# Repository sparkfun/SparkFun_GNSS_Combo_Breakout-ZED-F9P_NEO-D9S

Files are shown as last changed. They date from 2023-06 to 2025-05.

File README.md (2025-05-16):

# SparkFun u-blox ZED-F9P NEO-D9S Combo Breakout

<p align="center">
  <a href="https://github.com/sparkfun/SparkFun_GNSS_Combo_Breakout-ZED-F9P_NEO-D9S/issues" alt="Issues">
    </a>
  <a href="https://github.com/sparkfun/SparkFun_GNSS_Combo_Breakout-ZED-F9P_NEO-D9S/actions" alt="Actions">
    </a>
  <a href="https://github.com/sparkfun/SparkFun_GNSS_Combo_Breakout-ZED-F9P_NEO-D9S/blob/main/LICENSE.md" alt="License">
    </a>
  <a href="https://twitter.com/intent/follow?screen_name=sparkfun">
    </a>
</p>

SparkFun u-blox ZED-F9P NEO-D9S Combo Breakout (https://www.sparkfun.com/products/22560)

*[SparkFun u-blox ZED-F9P NEO-D9S Combo Breakout (GPS-22560)](https://www.sparkfun.com/products/22560)*

The [SparkFun u-blox ZED-F9P NEO-D9S Combo Breakout (GPS-22560)](https://www.sparkfun.com/products/22560) combines the u-blox ZED-F9P multi-band high precision GNSS module with the NEO-D9S L-band GNSS correction data receiver. With a clear view of the sky, especially a clear view to the South, this combo breakout will deliver centimeter-level accuracy positioning without needing separate RTK or NTRIP corrections.

The Combo Breakout is designed to work with u-blox's PointPerfect L-band satellite GNSS augmentation service, which provides homogeneous coverage in contiguous USA.

### Important Note:

u-blox provides products and services to "B2B Customers". Only business customers are eligible to register for a Thingstream (PointPerfect) account. You may be required to demonstrate that the use of the combo breakout is in relation to your trade, business, craft or profession. u-blox products and services are not intended for individual consumer use.

## Repository Contents

* **[/docs](/docs/)** - Online documentation files
    * [board_files](/docs/assets/board_files/) - Files for the product design
        * [Eagle design files](https://github.com/sparkfun/SparkFun_GNSS_Combo_Breakout-ZED-F9P_NEO-D9S/blob/main/docs/assets/board_files/ZED-F9P_NEO-D9S_Combo_x02.zip) (.zip)
        * [Schematic](https://github.com/sparkfun/SparkFun_GNSS_Combo_Breakout-ZED-F9P_NEO-D9S/blob/main/docs/assets/board_files/SparkFun_GNSS_Combo_Breakout-ZED-F9P_NEO-D9S_Schematic.pdf) (.pdf)
        * [Dimensions](https://github.com/sparkfun/SparkFun_GNSS_Combo_Breakout-ZED-F9P_NEO-D9S/blob/main/docs/assets/board_files/SparkFun_GNSS_Combo_Breakout-ZED-F9P_NEO-D9S_Dimensions.pn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) (.png)
* **[/Hardware](/Hardware/)** - Eagle design files (.brd, .sch)

## Documentation

* **[Hookup Guide (mkdocs)](http://docs.sparkfun.com/SparkFun_GNSS_Combo_Breakout-ZED-F9P_NEO-D9S/)** - Hookup guide for the SparkFun u-blox ZED-F9P NEO-D9S Combo Breakout hosted by GitHub pages.

## Product Versions

* [GPS-22560](https://www.sparkfun.com/products/22560) - Initial SparkFun Release

## License Information

This product is _**open source**_! 

Please review the LICENSE.md file for license information. 

If you have any questions or concerns on licensing, please contact technical support on our [SparkFun forums](https://forum.sparkfun.com/viewforum.php?f=152).

Distributed as-is; no warranty is given.

- Your friends at SparkFun.

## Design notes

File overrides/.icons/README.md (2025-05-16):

.icons directory
====================
This folder should contain branding logos for the product documentation

## General Images
- `sfe.svg` - SparkFun flame logo
- `kicad-primary.svg` - Full KiCad logo

## Directory
- `logo` - Other available logos

## SVG Optimizer
- [Remove meta data from svg](https://jakearchibald.github.io/svgomg/)

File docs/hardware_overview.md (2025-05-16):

<figure markdown>
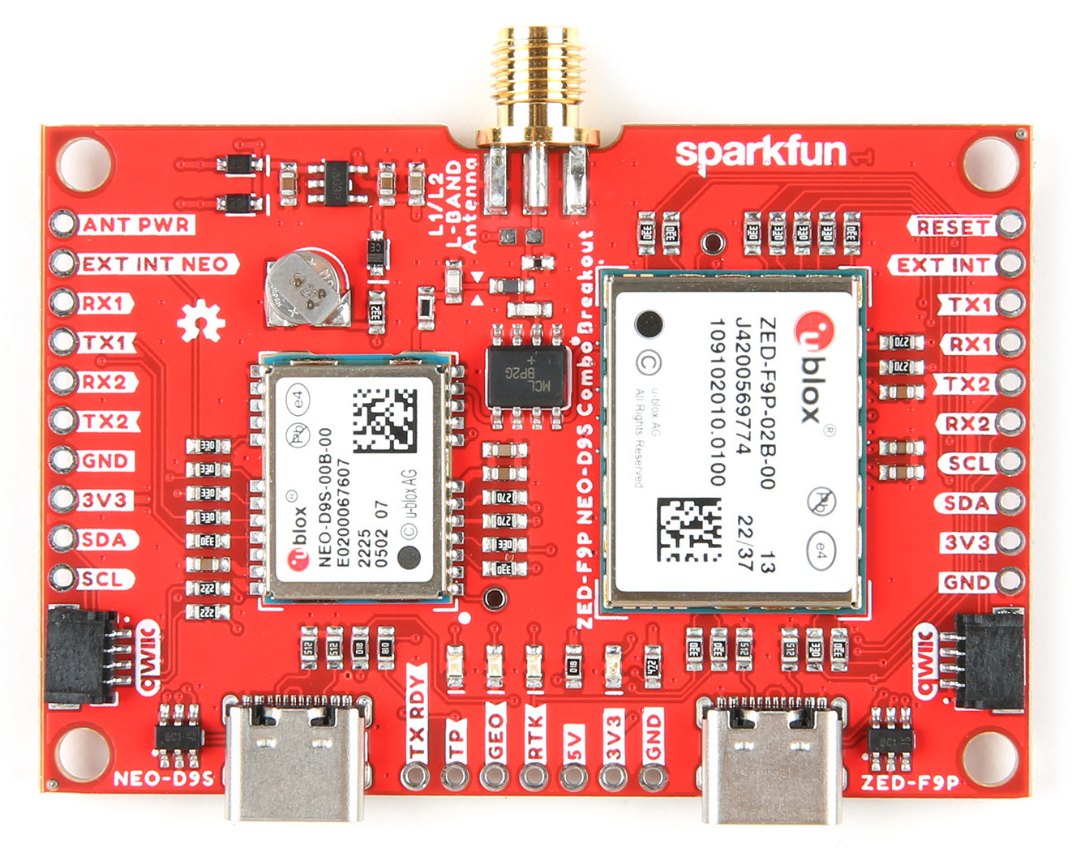
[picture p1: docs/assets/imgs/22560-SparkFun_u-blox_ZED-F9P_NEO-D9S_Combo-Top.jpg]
Combo Breakout PCB

<figcaption markdown>
The Combo Breakout PCB.
</figcaption>
</figure>

The u-blox ZED-F9P NEO-D9S Combo Breakout is a sophisticated yet compact GNSS board. The following is a summary of its features and functions:

* **`ZED-F9P`** - the ZED-F9P is a top-of-the-line module for high accuracy GNSS and GPS location solutions
    * Concurrent reception of GPS, GLONASS, Galileo and BeiDou
    * Multi-band RTK with fast convergence times and reliable performance
    * Centimeter-level accuracy in a small and energy-efficient module

<figure markdown>
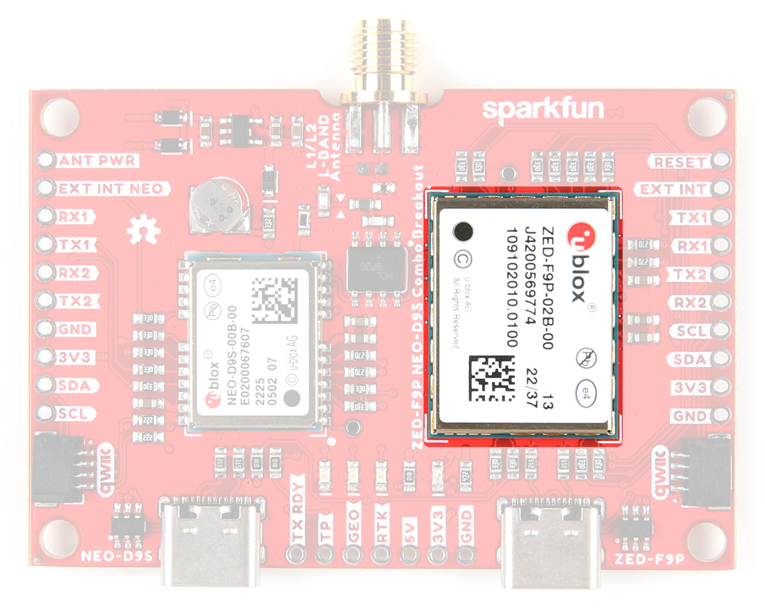
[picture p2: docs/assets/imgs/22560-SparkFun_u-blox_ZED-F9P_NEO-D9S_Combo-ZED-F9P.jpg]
ZED-F9P

<figcaption markdown>
The ZED-F9P GNSS module.
</figcaption>
</figure>

* **`NEO-D9S`** - the NEO-D9S is a satellite data receiver for L-band correction broadcast
    * The NEO-D9S can be configured for use with a variety of L-band correction services including u-blox's PointPerfect service
    * It decodes the satellite transmission and outputs a correction stream directly to the ZED-F9P via UART2

<figure markdown>
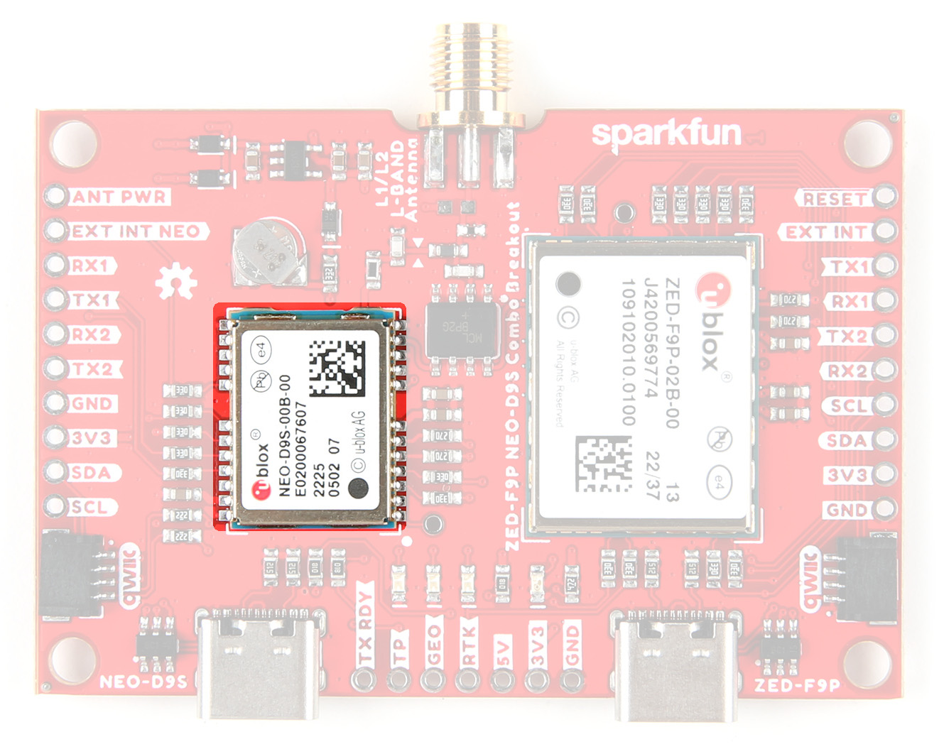
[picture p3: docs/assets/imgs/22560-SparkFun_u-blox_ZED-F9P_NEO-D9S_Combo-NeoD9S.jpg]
NEO-D9S

<figcaption markdown>
The NEO-D9S correction data receiver.
</figcaption>
</figure>

* **`UART2 TX and RX`** - the ZED-F9P and NEO-D9S UART2 TX and RX are interconnected (crossed-over) to allow the NEO to feed corrections directly to the ZED
    * The UART2 pins can be isolated if required by opening the **TX2** and **RX2** jumpers
    * Using UART2 to pass the correction data is recommended, but is optional. You can use UART1 or I<sup>2</sup>C instead if you want to. Our u-blox Arduino Library has an [example](https://github.com/sparkfun/SparkFun_u-blox_GNSS_v3/tree/main/examples/NEO-D9S_and_NEO-D9C/Example2_LBand_Corrections_with_NEO-D9S) which shows how to read the correction data from the NEO-D9S and push it to the ZED-F9P using I<sup>2</sup>C.

<figure markdown>
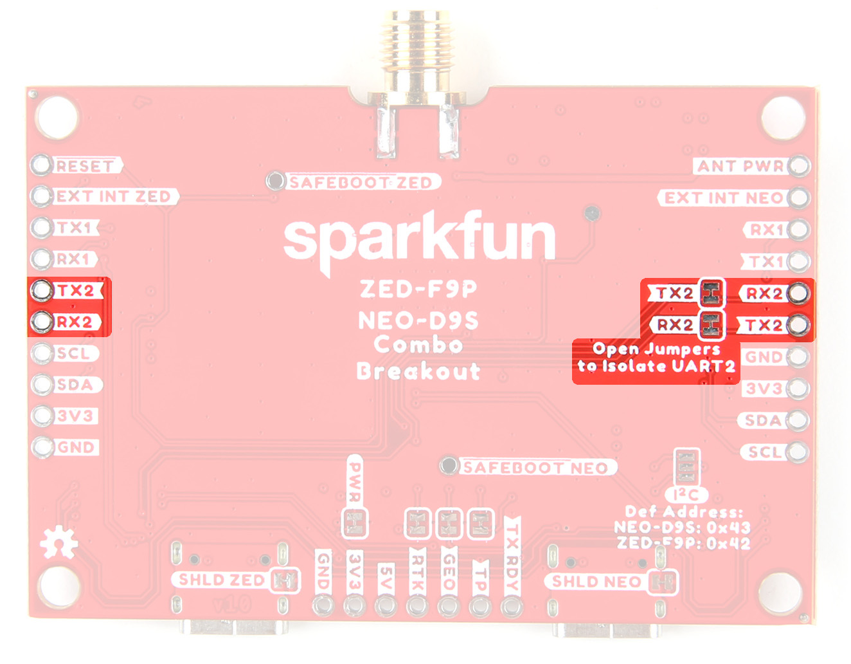
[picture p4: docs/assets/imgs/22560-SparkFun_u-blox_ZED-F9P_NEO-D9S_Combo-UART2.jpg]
UART2

<figcaption markdown>
The UART2 connections.
</figcaption>
</figure>

* **`Antenna Power Divider`** - the breakout has an on-board power divider (antenna splitter) to divide the satellite signals between the ZED and the NEO
    * The connector is SMA female (standard polarity)
    * 3.3V power is provided for an active antenna

<figure markdown>
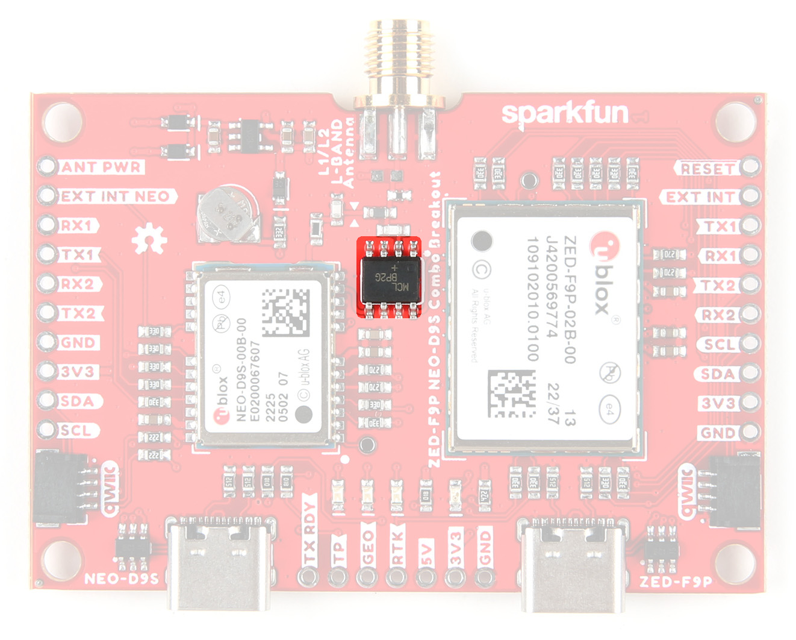
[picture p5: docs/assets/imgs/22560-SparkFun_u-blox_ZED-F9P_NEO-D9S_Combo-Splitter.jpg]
Splitter

<figcaption markdown>
The antenna splitter (power divider).
</figcaption>
</figure>

* **`Dual USB-C connections`** - one USB-C connector provides a direct connection to the ZED-F9P; the second provides a direct connection to the NEO-D9S
    * The board can be powered via either USB-C connector, or both
    * There is no on-board USB hub. Both ports can be connected simultaneously to the same computer, or different computers if desired

<figure markdown>
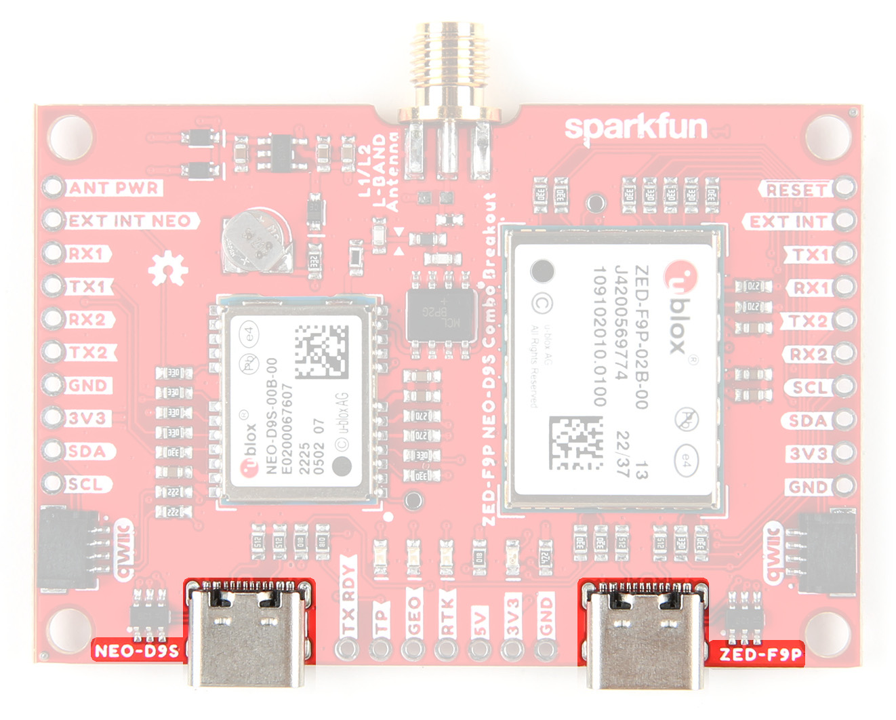
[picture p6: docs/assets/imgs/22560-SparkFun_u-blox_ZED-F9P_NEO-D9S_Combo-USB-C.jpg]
USB Connectors

<figcaption markdown>
The two USB-C connectors.
</figcaption>
</figure>

* **`LED Indicators`** - the breakout has four LED indicators:
    * **3V3** Power
    * **RTK**: Off = No Carrier Solution; Flashing = Floating Solution; On = Fixed Solution
    * **GEO**: Geofence indication
    * **TP**: Timing Pulse (Pulse Per Second)
    * Each LED can be disabled by opening the corresponding split pad jumper on the bottom of the breakout

<figure markdown>
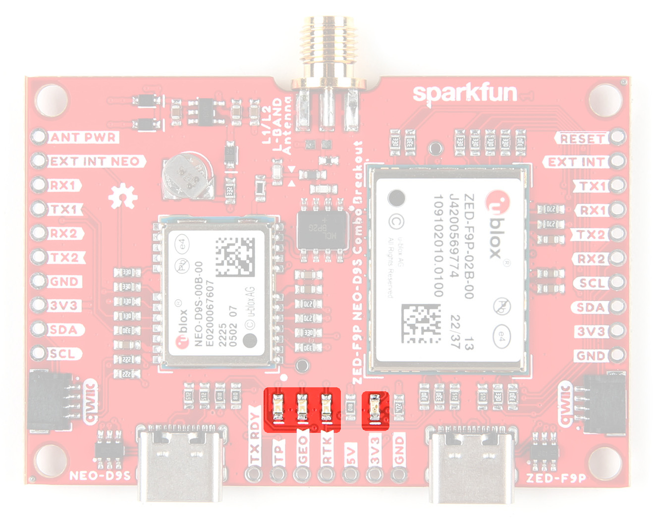
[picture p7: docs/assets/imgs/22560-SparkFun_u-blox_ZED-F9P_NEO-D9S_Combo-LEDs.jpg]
LEDs

<figcaption markdown>
The LEDs.
</figcaption>
</figure>

* **`Dual Qwiic Connectors`** - the breakout has two Qwiic (I<sup>2</sup>C) connectors allowing the breakout to be daisy-chained into your Qwiic project

<figure markdown>
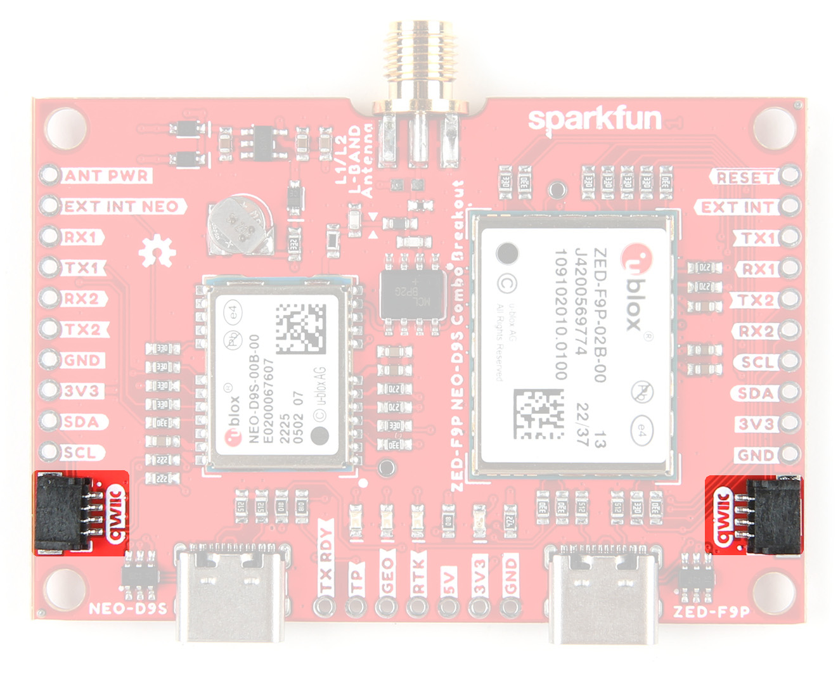
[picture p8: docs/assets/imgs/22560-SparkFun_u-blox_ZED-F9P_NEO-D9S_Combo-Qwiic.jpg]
Qwiic Connectors

<figcaption markdown>
The two Qwiic connectors.
</figcaption>
</figure>

* **`Back-up Battery`** - a small rechargeable coin cell maintains the ZED-F9P battery-backed RAM while the power is disconnected

<figure markdown>
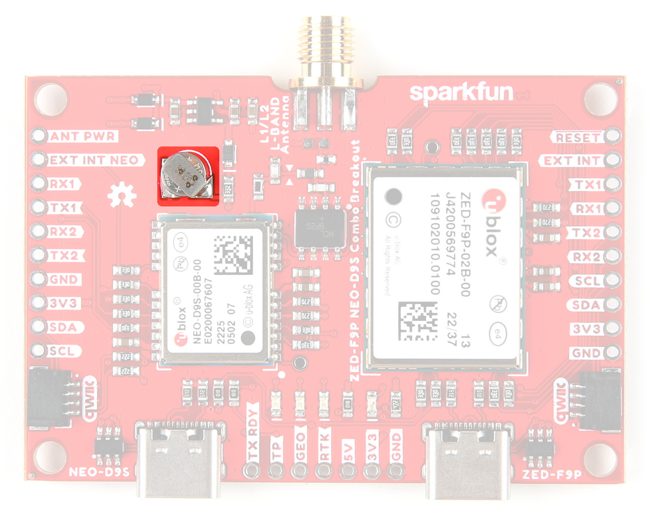
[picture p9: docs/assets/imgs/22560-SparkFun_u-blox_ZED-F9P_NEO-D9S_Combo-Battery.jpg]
Back-up Battery

<figcaption markdown>
The rechargeable back-up battery.
</figcaption>
</figure>

* **`Full set of breakout pads`** - the breakout pads provide full access to the ZED-F9P and NEO-D9S pins 
    * I<sup>2</sup>C
    * UART1
    * UART2
    * External Interrupt
    * Reset
    * Safeboot
    * ZED-F9P: TX_RDY, TP, GEO, RTK
    * Power: 5V and 3.3V

<figure markdown>
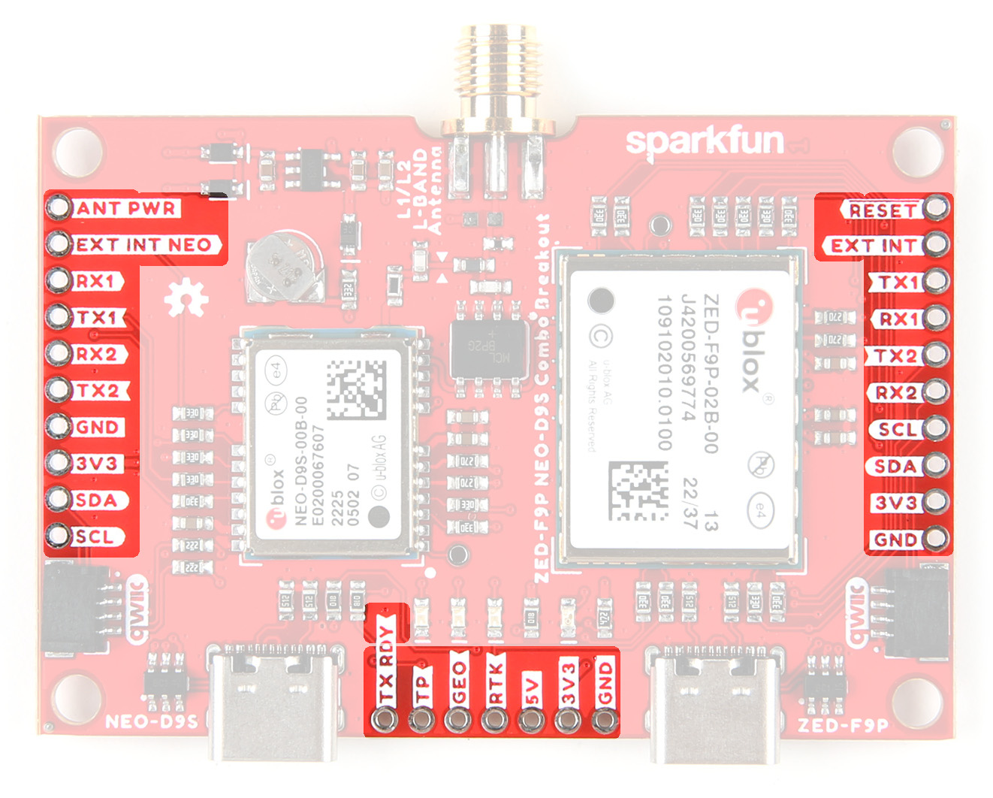
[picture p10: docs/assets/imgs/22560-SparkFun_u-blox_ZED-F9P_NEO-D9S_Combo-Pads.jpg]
Breakout Pads

<figcaption markdown>
The breakout pads.
</figcaption>
</figure>

## Board Dimensions

The board dimensions are illustrated in the drawing below. The listed measurements are in inches. The four mounting holes are compatible with 4-40 UNC or M3.0 screws.

<figure markdown>
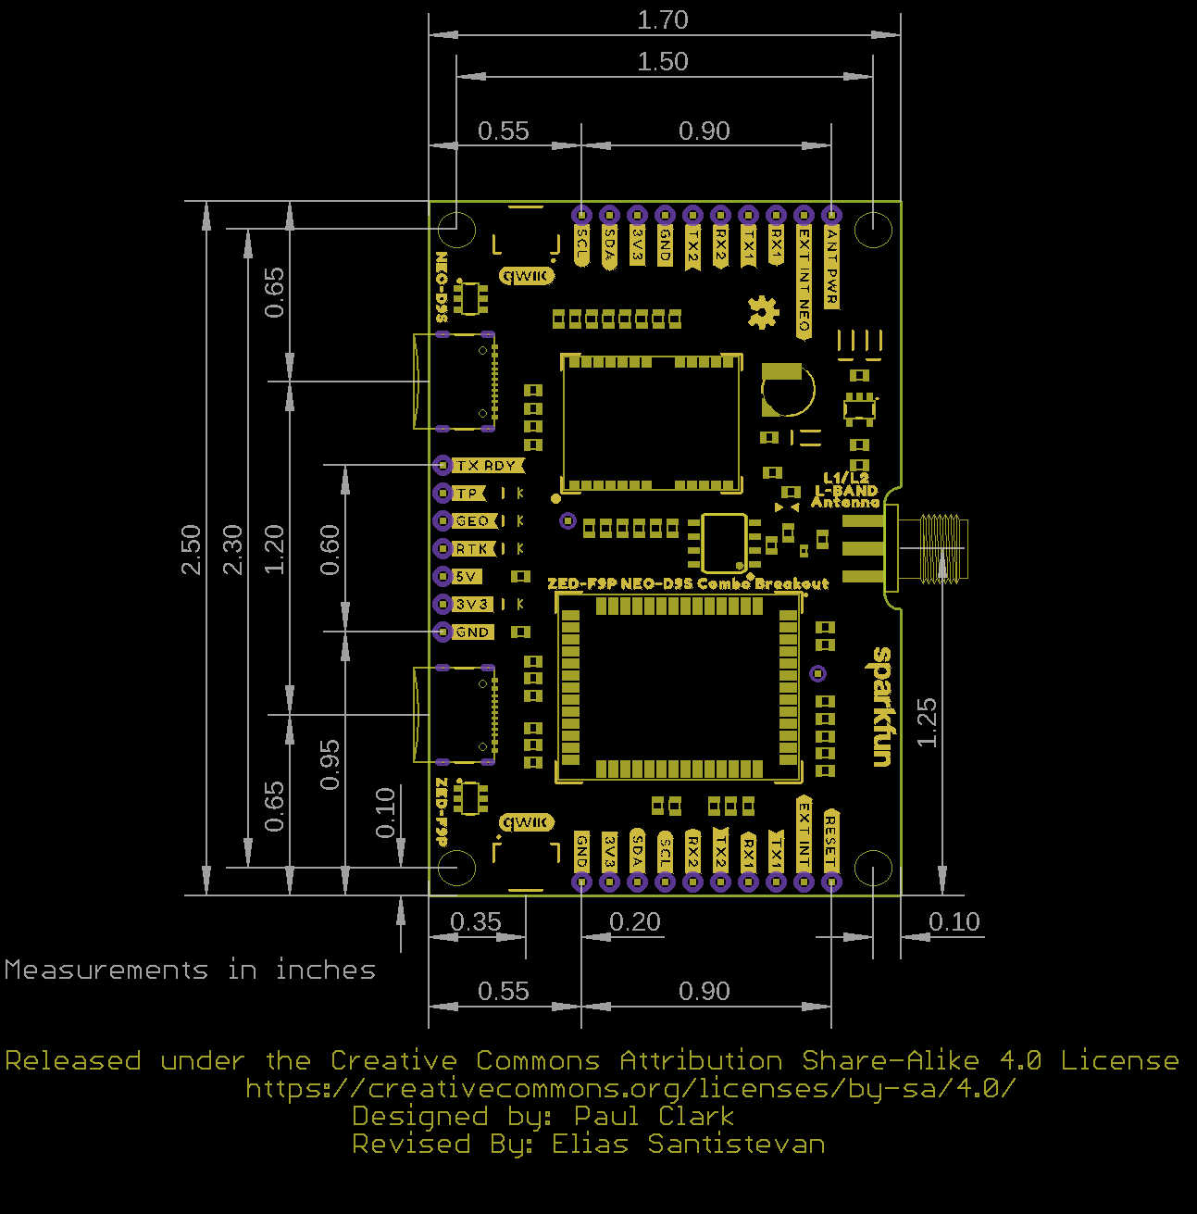
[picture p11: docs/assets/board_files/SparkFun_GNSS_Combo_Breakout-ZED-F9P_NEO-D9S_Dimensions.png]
Board Dimensions

<figcaption markdown>
Board dimensions.
</figcaption>
</figure>

## Left Edge Breakout Pads

With the SMA connector oriented to the 'top', the breakout pads down the left side of the board are:

<table style="font-size:12.25px; width:100%">
    <tr>
        <th style="text-align:center; vertical-align:middle; min-width:1rem;" width="20.0%">
            Pad
        </th>
        <th style="text-align:center; vertical-align:middle; min-width:4rem;" width="80.0%">
            Function
        </th>
    </tr>
    <tr>
        <td style="vertical-align:middle" align="center"><b>ANT_PWR</b></td>
        <td style="vertical-align:middle" align="center">External antenna power<br>Cut the <b>ANT_VCC</b> trace and install L1 to enable</td>
    </tr>
    <tr>
        <td style="vertical-align:middle" align="center"><b>EXT_INT_NEO</b></td>
        <td style="vertical-align:middle" align="center">Connected to the NEO-D9S EXT_INT pin</td>
    </tr>
    <tr>
        <td style="vertical-align:middle" align="center"><b>RX1</b></td>
        <td style="vertical-align:middle" align="center">NEO-D9S UART1 RX Pin</td>
    </tr>
    <tr>
        <td style="vertical-align:middle" align="center"><b>TX1</b></td>
        <td style="vertical-align:middle" align="center">NEO-D9S UART1 TX Pin</td>
    </tr>
    <tr>
        <td style="vertical-align:middle" align="center"><b>RX2</b></td>
        <td style="vertical-align:middle" align="center">NEO-D9S UART2 RX Pin<br>Connected to ZED-F9P TX2 (Open the <b>TX2</b> jumper to isolate)</td>
    </tr>
    <tr>
        <td style="vertical-align:middle" align="center"><b>TX2</b></td>
        <td style="vertical-align:middle" align="center">NEO-D9S UART2 TX Pin<br>Connected to ZED-F9P RX2 (Open the <b>RX2</b> jumper to isolate)</td>
    </tr>
    <tr>
        <td style="vertical-align:middle" align="center"><b>GND</b></td>
        <td style="vertical-align:middle" align="center">Power Ground (0V)</td>
    </tr>
    <tr>
        <td style="vertical-align:middle" align="center"><b>3V3</b></td>
        <td style="vertical-align:middle" align="center">3.3V Supply rail<br>Output of regulator U2 (Can also be used as a power input)</td>
    </tr>
    <tr>
        <td style="vertical-align:middle" align="center"><b>SDA</b></td>
        <td style="vertical-align:middle" align="center">I<sup>2</sup>C Data<br>Common to both ZED and NEO</td>
    </tr>
    <tr>
        <td style="vertical-align:middle" align="center"><b>SCL</b></td>
        <td style="vertical-align:middle" align="center">I<sup>2</sup>C Clock<br>Common to both ZED and NEO</td>
    </tr>
</table>

*For more details, users can reference the [schematic](assets/board_files/SparkFun_GNSS_Combo_Breakout-ZED-F9P_NEO-D9S_Schematic.pdf).*

## Right Edge Breakout Pads

With the SMA connector oriented to the 'top', the breakout pads down the right side of the board are:

<table style="font-size:12.25px; width:100%">
    <tr>
        <th style="text-align:center; vertical-align:middle; min-width:1rem;" width="20.0%">
            Pad
        </th>
        <th style="text-align:center; vertical-align:middle; min-width:4rem;" width="80.0%">
            Function
        </th>
    </tr>
    <tr>
        <td style="vertical-align:middle" align="center"><b>RESET</b></td>
        <td style="vertical-align:middle" align="center">Reset<br>Active low. Common to both ZED and NEO</td>
    </tr>
    <tr>
        <td style="vertical-align:middle" align="center"><b>EXT_INT</b></td>
        <td style="vertical-align:middle" align="center">Connected to the ZED-F9P EXT_INT pin</td>
    </tr>
    <tr>
        <td style="vertical-align:middle" align="center"><b>TX1</b></td>
        <td style="vertical-align:middle" align="center">ZED-F9P UART1 TX Pin</td>
    </tr>
    <tr>
        <td style="vertical-align:middle" align="center"><b>RX1</b></td>
        <td style="vertical-align:middle" align="center">ZED-F9P UART1 RX Pin</td>
    </tr>
    <tr>
        <td style="vertical-align:middle" align="center"><b>TX2</b></td>
        <td style="vertical-align:middle" align="center">ZED-F9P UART2 TX Pin<br>Connected to NEO-D9S RX2 (Open the <b>TX2</b> jumper to isolate)</td>
    </tr>
    <tr>
        <td style="vertical-align:middle" align="center"><b>RX2</b></td>
        <td style="vertical-align:middle" align="center">ZED-F9P UART2 RX Pin<br>Connected to NEO-D9S TX2 (Open the <b>RX2</b> jumper to isolate)</td>
    </tr>
    <tr>
        <td style="vertical-align:middle" align="center"><b>SCL</b></td>
        <td style="vertical-align:middle" align="center">I<sup>2</sup>C Clock<br>Common to both ZED and NEO</td>
    </tr>
    <tr>
        <td style="vertical-align:middle" align="center"><b>SDA</b></td>
        <td style="vertical-align:middle" align="center">I<sup>2</sup>C Data<br>Common to both ZED and NEO</td>
    </tr>
    <tr>
        <td style="vertical-align:middle" align="center"><b>3V3</b></td>
        <td style="vertical-align:middle" align="center">3.3V Supply rail<br>Output of regulator U2 (Can be used as a power input)</td>
    </tr>
    <tr>
        <td style="vertical-align:middle" align="center"><b>GND</b></td>
        <td style="vertical-align:middle" align="center">Power Ground (0V)</td>
    </tr>
</table>

*For more details, users can reference the [schematic](assets/board_files/SparkFun_GNSS_Combo_Breakout-ZED-F9P_NEO-D9S_Schematic.pdf).*

## Right Edge Breakout Pads

With the SMA connector oriented to the 'top', the breakout pads along the bottom edge of the board are:

<table style="font-size:12.25px; width:100%">
    <tr>
        <th style="text-align:center; vertical-align:middle; min-width:1rem;" width="20.0%">
            Pad
        </th>
        <th style="text-align:center; vertical-align:middle; min-width:4rem;" width="80.0%">
            Function
        </th>
    </tr>
    <tr>
        <td style="vertical-align:middle" align="center"><b>TX_RDY</b></td>
        <td style="vertical-align:middle" align="center">Indicates the ZED-F9P has data waiting in its I<sup>2</sup>C TX buffer</td>
    </tr>
    <tr>
        <td style="vertical-align:middle" align="center"><b>TP</b></td>
        <td style="vertical-align:middle" align="center">ZED-F9P Timing Pulse (Pulse Per Second)</td>
    </tr>
    <tr>
        <td style="vertical-align:middle" align="center"><b>GEO</b></td>
        <td style="vertical-align:middle" align="center">ZED-F9P Geofence indicator</td>
    </tr>
    <tr>
        <td style="vertical-align:middle" align="center"><b>RTK</b></td>
        <td style="vertical-align:middle" align="center">ZED-F9P RTK indication<br>High = No Carrier Solution. Square Wave = Floating Solution. Low = Fixed Solution</td>
    </tr>
    <tr>
        <td style="vertical-align:middle" align="center"><b>5V</b></td>
        <td style="vertical-align:middle" align="center">5V Power Rail<br>Can be used as a power input or output (from USB) (Diode protected)</td>
    </tr>
    <tr>
        <td style="vertical-align:middle" align="center"><b>3V3</b></td>
        <td style="vertical-align:middle" align="center">3.3V Supply rail<br>Output of regulator U2 (Can be used as a power input)</td>
    </tr>
    <tr>
        <td style="vertical-align:middle" align="center"><b>GND</b></td>
        <td style="vertical-align:middle" align="center">Power Ground (0V)</td>
    </tr>
</table>

*For more details, users can reference the [schematic](assets/board_files/SparkFun_GNSS_Combo_Breakout-ZED-F9P_NEO-D9S_Schematic.pdf).*

## Jumpers

!!! note
    <p>Never modified a jumper before? Check out our <a href="https://learn.sparkfun.com/tutorials/664">Jumper Pads and PCB Traces tutorial</a> for a quick introduction!</p>
    <p align="center">
        <a href="https://learn.sparkfun.com/tutorials/664">How to Work with Jumper Pads and PCB Traces<br>
        </a>
    </p>

There are multiple jumpers on the back of the board that can be used to modify how the board functions.

<figure markdown>
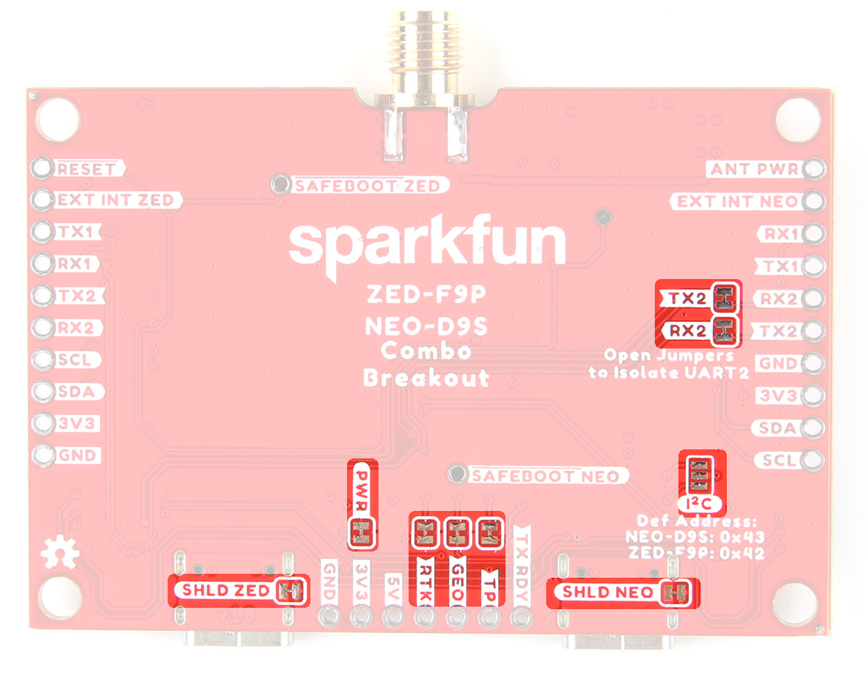
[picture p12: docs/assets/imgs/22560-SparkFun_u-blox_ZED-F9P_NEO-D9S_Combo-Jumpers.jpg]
Jumpers

<figcaption markdown>
The jumpers on the back of the board.
</figcaption>
</figure>

* **TX2** - open this jumper to isolate NEO-D9S RX2 from ZED-F9P TX2
* **RX2** - open this jumper to isolate NEO-D9S TX2 from ZED-F9P RX2
    * By default, the NEO-D9S PMP (SPARTN) correction data stream is output directly from NEO-D9S TX2 to the ZED-F9P RX2
    * Opening this jumper will break that connection
    * Correction data can be read from the NEO-D9S and pushed to the ZED-F9P via I<sup>2</sup>C instead
* **I<sup>2</sup>C** - close this double jumper to connect additional pull-up resistors to I<sup>2</sup>C **SCL** and **SDA**. Not recommended
* **SHLD** - the two **SHLD** jumpers can be opened to isolate the USB-C connector shields from **GND**. Not recommended, but may help prevent EMI
* **PWR** - open this jumper to disable the Power LED
* **RTK** - open this jumper to disable the RTK LED
* **GEO** - open this jumper to disable the GEO LED
* **TP** - open this jumper to disable the TP (PPS) LED

## ANT PWR

By default, 3.3V active antenna power is provided on the SMA connector via the NEO-D9S **VCC_RF** output pin.
Power is delivered via a 10 Ohm resistor, to limit the current in case the antenna cable becomes shorted.

If your antenna requires a higher voltage (or current):

* Isolate **VCC_RF** by cutting the trace marked by the arrow symbols on the top of the PCB

<figure markdown>
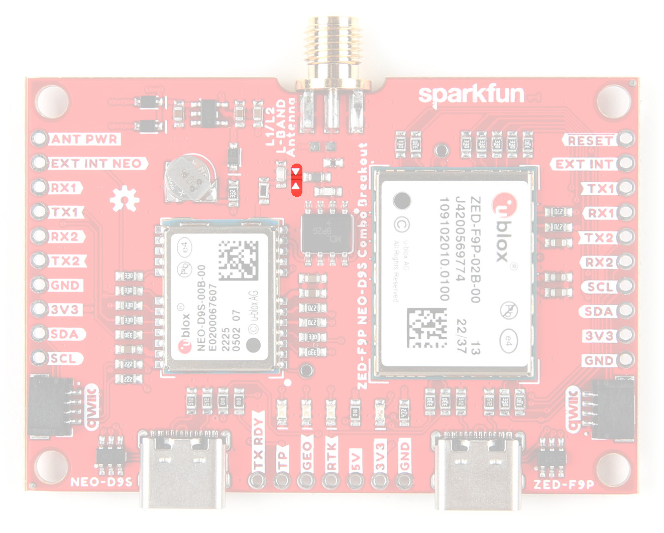
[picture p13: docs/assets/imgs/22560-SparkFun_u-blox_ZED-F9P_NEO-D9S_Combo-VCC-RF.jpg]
VCC_RF

<figcaption markdown>
The VCC_RF trace.
</figcaption>
</figure>

* Install inductor L1 - using a 0603 inductor with impedance >500 Ohms at 1.5 GHz

<figure markdown>
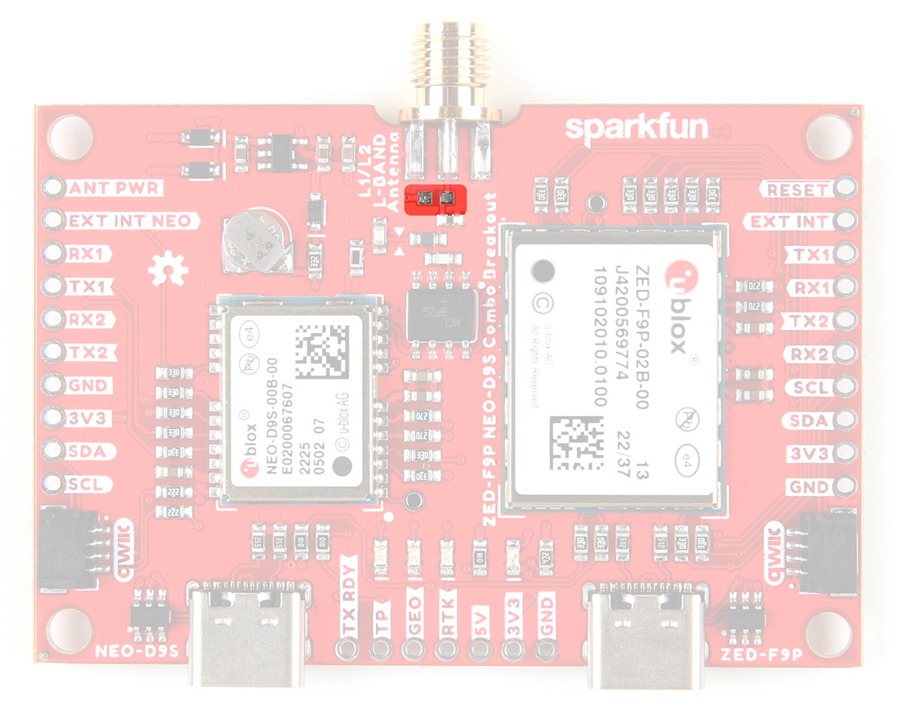
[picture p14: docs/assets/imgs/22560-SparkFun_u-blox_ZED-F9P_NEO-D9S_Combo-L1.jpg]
L1

<figcaption markdown>
The position of L1.
</figcaption>
</figure>

* Inject a **clean** DC supply voltage between the **ANT PWR** breakout pad and **GND**

## SAFEBOOT

It _may_ be necessary to place the ZED-F9P or NEO-D9S into a "safe boot" state before applying a firmware upgrade.

If this becomes necessary:

* Disconnect power to the breakout board
* For the ZED-F9P: connect a jumper wire between the **SAFEBOOT ZED** test point and **GND**
* Reconnect the power
* Disconnect the jumper
* Upgrade the firmware using u-center

Repeat for the NEO-D9S using the **SAFEBOOT NEO** test point.

<figure markdown>
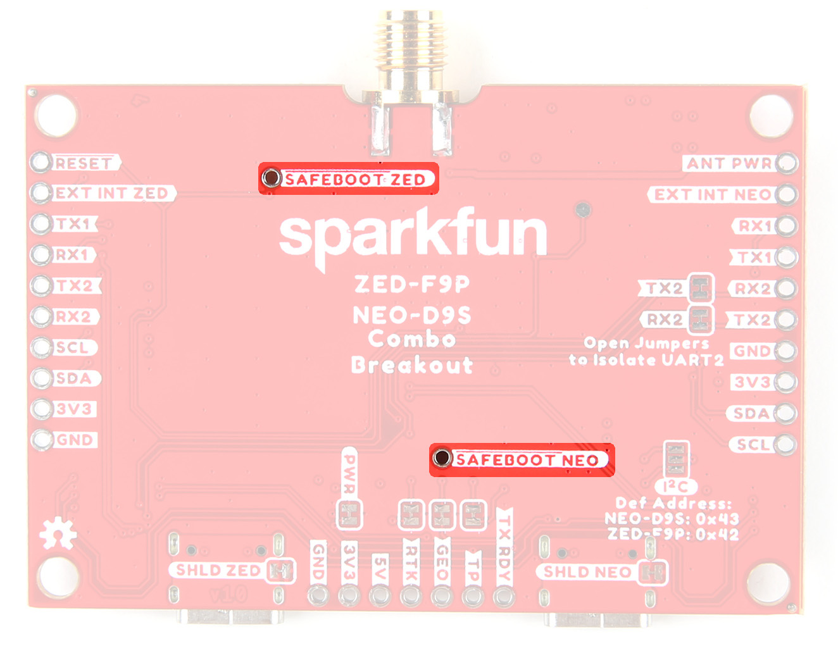
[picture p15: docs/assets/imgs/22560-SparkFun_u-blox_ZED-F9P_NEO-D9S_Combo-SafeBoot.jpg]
The two SAFEBOOT test points

<figcaption markdown>
The two SAFEBOOT test points.
</figcaption>
</figure>

## LED Indicators

The breakout has four LED indicators:

* **3V3** Power
* **RTK**: Off = No Carrier Solution; Flashing = Floating Solution; On = Fixed Solution
* **GEO**: Geofence indication
* **TP**: Timing Pulse (Pulse Per Second)

Each LED can be disabled by opening the corresponding split pad jumper on the bottom of the breakout

## Back-up Battery

A small rechargeable coin cell maintains the ZED-F9P battery-backed RAM while the power is disconnected. It maintains the ZED's GNSS Almanac and Real Time Clock.

The battery is recharged slowly whenever 3.3V power is present.

If the battery becomes discharged, connect 3.3V power for at least 48 hours to recharge the battery.

## Power Supply and I/O voltage

Both the ZED-F9P and NEO-D9S are 3.3V devices. They operate from 3.3V and all of their I/O pins are 3.3V.

!!! attention
    Do not drive any of the ZED-F9P or NEO-D9S I/O pins using 5V signals. You may damage either or both modules if you do. Use a suitable level-shifter if you want to interface to a 5V development board.

The board has a 3.3V regulator on-board to regulate 5V USB-C power (if present) down to 3.3V.

The options for providing power to the board are as follows:

* 5V power via one or both USB-C ports
    * Diode protection is provided
* 5V power via the **5V** breakout pin
    * Diode protection prevents the USB-C ports from being reverse-fed
* 3.3V power via:
    * Either of the Qwiic connectors
    * Any of the **3V3** breakout pins

## Current Draw

Worst-case current draw of the ZED-F9P and NEO-D9S combined is 260mA at 3.3V.

Typical current draw of the ZED-F9P and NEO-D9S combined is 100mA.

(These figures exclude any current drawn by an active antenna.)

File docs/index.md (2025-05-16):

<link rel="stylesheet" href="https://cdnjs.cloudflare.com/ajax/libs/font-awesome/4.7.0/css/font-awesome.min.css">

<div class="grid cards desc" markdown>

- <figure markdown>
    SparkFun GNSS Combo Breakout - ZED-F9P, NEO-D9S (Qwiic) (https://www.sparkfun.com/products/22560)
		</figure>

    <center>
    [Purchase from SparkFun](https://www.sparkfun.com/products/22560){ .md-button .md-button--primary }
    </center>

- The SparkFun GNSS Combo Breakout - ZED-F9P, NEO-D9S (Qwiic) (GPS-22560) combines the u-blox ZED-F9P multi-band high precision GNSS module with the NEO-D9S L-band GNSS correction data receiver. With a clear view of the sky, especially a clear view to the South, this combo breakout will deliver centimeter-level accuracy positioning without needing separate RTK or NTRIP corrections. An on-board splitter (power divider) allows you to connect both modules to a single L1/L2 L-Band antenna.

</div>

The Combo Breakout is designed to work with u-blox's PointPerfect L-band satellite GNSS augmentation service, which provides homogeneous coverage in contiguous USA.

!!! warning
    u-blox provides products and services to "B2B Customers". Only business customers are eligible to register for a Thingstream (PointPerfect) account. You may be required to demonstrate that the use of the combo breakout is in relation to your trade, business, craft or profession. u-blox products and services are not intended for individual consumer use. Please check the [u-blox Service Terms](https://cdn.sparkfun.com/assets/2/5/a/4/f/Service_Terms.pdf) before purchasing hardware.

## Required Materials

Before you begin, you need to think about how you will use the SparkFun GNSS Combo Breakout - ZED-F9P, NEO-D9S (Qwiic).

The Combo Breakout is a very versatile board, combining the u-blox ZED-F9P multi-band high precision GNSS module with the NEO-D9S L-band GNSS correction data receiver.

<figure markdown>
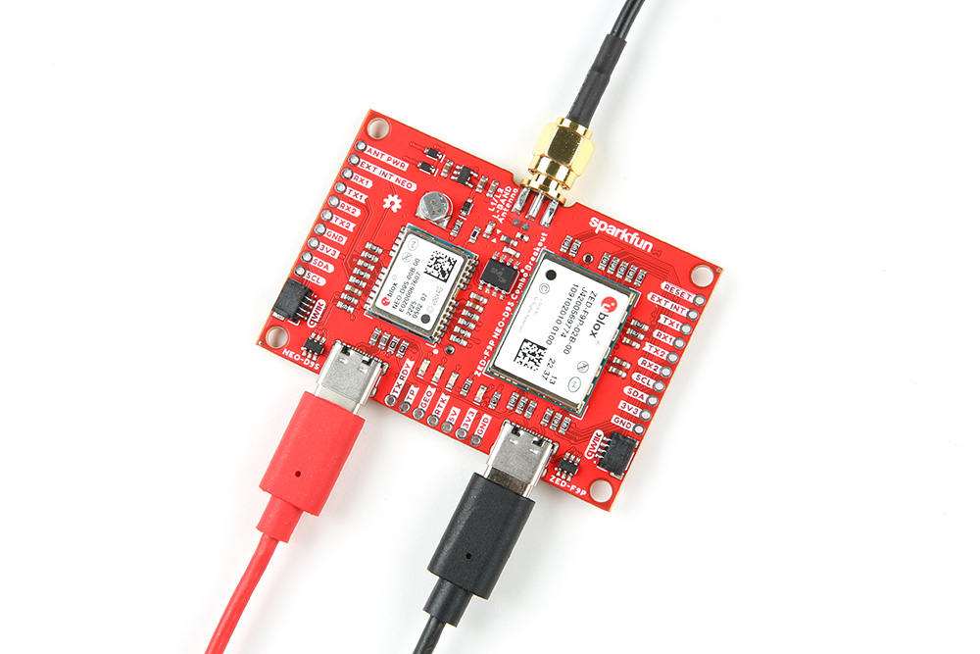
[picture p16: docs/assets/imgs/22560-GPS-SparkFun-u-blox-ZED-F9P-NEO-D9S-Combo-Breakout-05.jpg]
Hookup for u-center with two USB cables

<figcaption markdown>
Hookup for u-center with two USB cables.
</figcaption>
</figure>

If you intend to use [u-blox's u-center (GNSS evaluation software for Windows)](https://www.u-blox.com/en/product/u-center) to configure both the ZED-F9P and the NEO-D9S and log data from the ZED-F9P, all you need to get started is a pair of USB cables and a suitable antenna. u-blox have written an
[excellent application note](https://www.u-blox.com/sites/default/files/documents/NEO-D9S_ZED-F9_Config_SPARTN_AppNote_UBX-22008160.pdf) which shows how to configure both modules using u-center.

<table style="border-style:none">
    <tr>
        <td>
            <a href="https://www.sparkfun.com/products/17751">
                <center>GNSS Multi-Band L1/L2 Surveying Antenna (TNC) - TOP106</center>
                <h3 class="title">GNSS Multi-Band L1/L2 Surveying Antenna (TNC) - TOP106</h3>
            </a>
            GPS-17751
        </td>
        <td>
            <a href="https://www.sparkfun.com/products/21281">
                <center>Interface Cable - SMA Female to SMA Male (10m, RG58)
                </center>
                <h3 class="title">Interface Cable - SMA Female to SMA Male (10m, RG58)</h3>
            </a>
            CAB-21281
        </td>
    </tr>
</table>

The Combo Breakout has a single female SMA socket for the antenna connection. An on-board splitter (power divider) allows the ZED-F9P and NEO-D9S to share a single antenna. You need an antenna which supports both L1 and L2 GNSS, and which also provides broad coverage of the L-Band for the correction signal. Our TOP-106 antenna is a good choice. It has a TNC connection, so you may also want to purchase a SMA to TNC interface cable and/or a SMA female to male extension cable, depending on your needs:

<table style="border-style:none">
    <tr>
        <td>
            <a href="https://www.sparkfun.com/products/17833">
                <center>Interface Cable - SMA Male to TNC Male (300mm)</center>
                <h3 class="title">Interface Cable - SMA Male to TNC Male (300mm)</h3>
            </a>
            CAB-17833
        </td>
        <td>
            <a href="https://www.sparkfun.com/products/12861">
                <center>Interface Cable - SMA Female to SMA Male (25cm)
                </center>
                <h3 class="title">Interface Cable - SMA Female to SMA Male (25cm)</h3>
            </a>
            WRL-12861
        </td>
    </tr>
</table>

!!! warning
    While we were able to get the <a href="https://www.sparkfun.com/products/15192">GNSS L1/L2 Multi-Band Magnetic Mount Antenna - 5m (SMA), ANN-MB-00</a> to work with the NEO-D9S in the US, we recommend using a dedicated L1/L2/L-Band antenna for best results. 

## Getting Started with Arduino

<figure markdown>
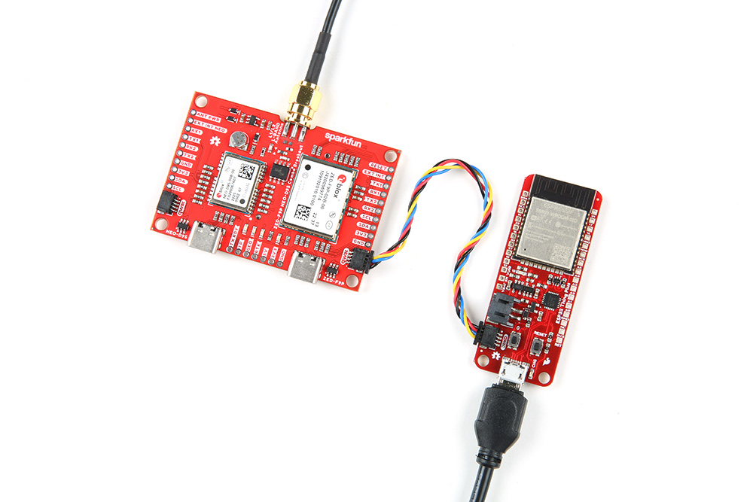
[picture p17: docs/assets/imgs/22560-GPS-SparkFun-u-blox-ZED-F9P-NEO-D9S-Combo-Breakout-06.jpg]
Hookup for Arduino using Qwiic

<figcaption markdown>
Hookup for Arduino using Qwiic.
</figcaption>
</figure>

It is also possible to power the board and communicate with it using I<sup>2</sup>C by connecting to either of the board's **Qwiic** connectors. SparkFun's [Qwiic Connect System](https://www.sparkfun.com/qwiic) uses 4-pin JST connectors, allowing you to quickly interface your development board to the Combo Board.

Our [u-blox GNSS Arduino Library - v3](https://github.com/sparkfun/SparkFun_u-blox_GNSS_v3) contains a comprehensive set of tried and tested examples that will work
on any Qwiic-enabled development board. There are dedicated examples for the ZED-F9P and NEO-D9S.

You can also use 3.3V Serial (UART) to communicate with both the ZED-F9P and NEO-D9S. Our Arduino Library supports both Serial and I<sup>2</sup>C. (It supports SPI too, but SPI
is not supported on the Combo Breakout).

When choosing a development board, you might want to choose one which has built-in WiFi. The correction data received by the NEO-D9S is encrypted, you need to pass keys to the
ZED-F9P so it can decrypt the data. A WiFi connection will allow you to download the PointPerfect SPARTN encryption keys directly from u-blox's Thingstream IoT service using MQTT.

You might also find a microSD card socket useful for data logging. If you want to log data while you are out in the field, being able to connect a Li-Po battery will be useful too.

These two ESP32 development boards support: Qwiic, Serial, WiFi, microSD and Li-Po.

<table style="border-style:none">
    <tr>
        <td>
            <a href="https://www.sparkfun.com/products/20168">
                <center>SparkFun Thing Plus - ESP32 WROOM (USB-C)</center>
                <h3 class="title">SparkFun Thing Plus - ESP32 WROOM (USB-C)</h3>
            </a>
            WRL-20168
        </td>
        <td>
            <a href="https://www.sparkfun.com/products/19177">
                <center>SparkFun IoT RedBoard - ESP32 Development Board
                </center>
                <h3 class="title">SparkFun IoT RedBoard - ESP32 Development Board</h3>
            </a>
            WRL-19177
        </td>
    </tr>
    <tr>
        <td>
            <a href="https://www.sparkfun.com/products/15081">
                <center>SparkFun Qwiic Cable Kit</center>
                <h3 class="title">SparkFun Qwiic Cable Kit</h3>
            </a>
            KIT-15081
        </td>
        <td>
            <a href="https://www.sparkfun.com/products/14743">
                <center>USB 3.1 Cable A to C - 3 Foot
                </center>
                <h3 class="title">USB 3.1 Cable A to C - 3 Foot</h3>
            </a>
            CAB-14743
        </td>
    </tr>
</table>

## Li-Po Battery
<p>For mobile applications, users will want to pick up a <a href="https://www.sparkfun.com/categories/54">single-cell LiPo battery</a> from our catalog. Below, are a few available options:</p>

<table style="border-style:none">
    <tr>
        <td>
            <a href="https://www.sparkfun.com/products/13855">
                <center>Lithium Ion Battery - 2Ah</center>
                <h3 class="title">Lithium Ion Battery - 2Ah</h3>
            </a>
            PRT-13855
        </td>
        <td>
            <a class="thumb" href="https://www.sparkfun.com/products/13851">
                <center>Lithium Ion Battery - 400mAh
                </center>
                <h3 class="title">Lithium Ion Battery - 400mAh</h3>
            </a>
            PRT-13851
        </td>
        <td>
            <a class="thumb" href="https://www.sparkfun.com/products/13813">
                <center>Lithium Ion Battery - 1Ah
                </center>
                <h3 class="title">Lithium Ion Battery - 1Ah</h3>
            </a>
            PRT-13813
        </td>
    </tr>
</table>

## Jumper Modification

<p>To modify the jumpers, users will need <a href="https://www.sparkfun.com/categories/49">soldering equipment</a> and/or a <a href="https://www.sparkfun.com/categories/379">knife</a>.</p>

<table style="border-style:none">
    <tr>
        <td>
            <a href="https://www.sparkfun.com/products/9325">
                <center>Solder Lead Free - 100-gram Spool</center>
                <h3 class="title">Solder Lead Free - 100-gram Spool</h3>
            </a>
            TOL-09325
        </td>
        <td>
            <a class="thumb" href="https://www.sparkfun.com/products/14228">
                <center>Weller WLC100 Soldering Station
                </center>
                <h3 class="title">Weller WLC100 Soldering Station</h3>
            </a>
            TOL-14228
        </td>
        <td>
            <a class="thumb" href="https://www.sparkfun.com/products/14579">
                <center>Chip Quik No-Clean Flux Pen - 10mL
                </center>
                <h3 class="title">Chip Quik No-Clean Flux Pen - 10mL</h3>
            </a>
            TOL-14579
        </td>
        <td>
            <a class="thumb" href="https://www.sparkfun.com/products/9200">
                <center>Hobby Knife
                </center>
                <h3 class="title">Hobby Knife</h3>
            </a>
            TOL-09200
        </td>
    </tr>
</table>

!!! note
    <p>New to jumper pads? Check out our <a href="https://learn.sparkfun.com/tutorials/664">Jumper Pads and PCB Traces Tutorial</a> for a quick introduction!</p>
    <p align="center">
        <a href="https://learn.sparkfun.com/tutorials/664">How to Work with Jumper Pads and PCB Traces<br>
        </a>
    </p>

## Suggested Reading

As a more professionally oriented product, we will skip over the more fundamental tutorials (i.e. [**Ohm's Law**](https://learn.sparkfun.com/tutorials/voltage-current-resistance-and-ohms-law) and [**What is Electricity?**](https://learn.sparkfun.com/tutorials/what-is-electricity)). However, below are a few tutorials that may help users familiarize themselves with various aspects of the board.

<table style="border-style:none">
    <tr>
        <td align="center">
            <a href="https://learn.sparkfun.com/tutorials/61">Installing the Arduino IDE<br>
            </a>
        </td>
        <td align="center">
            <a href="https://learn.sparkfun.com/tutorials/1265">Installing Board Definitions in the Arduino IDE<br>
            </a>
        </td>
        <td align="center">
            <a href="https://learn.sparkfun.com/tutorials/12">Installing an Arduino Library<br>
            </a>
        </td>
    </tr>
    <tr>
        <td align="center">
            <a href="https://learn.sparkfun.com/tutorials/908">How to Install CH340 Drivers<br>
            </a>
        </td>
        <td align="center">
            <a href="https://learn.sparkfun.com/tutorials/5">How to Solder: Through-Hole Soldering<br>
            </a>
        </td>
        <td align="center">
            <a href="https://learn.sparkfun.com/tutorials/664">How to Work with Jumper Pads and PCB Traces<br>
            </a>
        </td>
    </tr>
    <tr>
        <td align="center">
            <a href="https://learn.sparkfun.com/tutorials/8">Serial Communication<br>
            </a>
        </td>
        <td align="center">
            <a href="https://learn.sparkfun.com/tutorials/89">Analog vs. Digital<br>
            </a>
        </td>
        <td align="center">
            <a href="https://learn.sparkfun.com/tutorials/51">Pulse Width Modulation<br>
            </a>
        </td>
    </tr>
    <tr>
        <td align="center">
            <a href="https://learn.sparkfun.com/tutorials/62">Logic Levels<br>
            </a>
        </td>
        <td align="center">
            <a href="https://learn.sparkfun.com/tutorials/82">I2C<br>
            </a>
        </td>
        <td align="center">
            <a href="https://learn.sparkfun.com/tutorials/16">Serial Peripheral Interface (SPI)<br>
            </a>
        </td>
    </tr>
</table>

<center>
<div align="center">
    <div style="top:5px;left:5px;background-color:Gray;position:relative">
        <div style="top:-5px;left:-5px;background-color:#ffffff;position:relative;border:1px solid black;">
            <a href="https://www.sparkfun.com/qwiic">Qwiic Connect System</a>
        </div>
    </div>
</div>
</center>

One of the new, advanced features of our Processor Boards is that they take advantage of the [Qwiic connect system](https://www.sparkfun.com/qwiic). We recommend familiarizing yourself with the **Logic Levels** and **I<sup>2</sup>C** tutorials.  Click on the banner above to learn more about [Qwiic products](https://www.sparkfun.com/qwiic).

<center>
    <iframe width="600" height="327" src="https://www.youtube.com/embed/x0RDEHqFIF8" title="SparkFun's Qwiic Connect System" frameborder="0" allow="accelerometer; autoplay; clipboard-write; encrypted-media; gyroscope; picture-in-picture" allowfullscreen></iframe>
</center>

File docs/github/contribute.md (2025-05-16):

## Make an Augmentation!
Spot an improvement opportunity? Feel free to contribute to our open-source design and documentation. 

## :material-file-document-multiple:&nbsp;Improve our Documentation
All of this documentation can be modified by you! Please help us make it better.

- These pages are contained in the [`docs` folder](https://github.com/sparkfun/SparkFun_GNSS_Combo_Breakout-ZED-F9P_NEO-D9S/tree/main/docs) of the [SparkFun GNSS Combo Breakout - ZED-F9P, NEO-D9S repository](https://github.com/sparkfun/SparkFun_GNSS_Combo_Breakout-ZED-F9P_NEO-D9S).

<!-- ### :material-source-pull:&nbsp;Submit a Correction -->
### Submit a Correction

1. With a GitHub account, [fork this repository](https://github.com/sparkfun/SparkFun_GNSS_Combo_Breakout-ZED-F9P_NEO-D9S/fork).
2. Add your corrections or improvements to the markdown file.
3. File a pull request with your changes, and enjoy making the ~~words~~ ~~worlds~~ world a better place.
	- Once received, the documentation specialist will automatically be notified.
	- We will review your suggested improvements to make sure they are correct and fit within our documentation standards.

## :material-cog:&nbsp;Improve our Hardware Design
All of our designs are open-source! Please help us make it better.

- Our board design files are contained in the `/Hardware` directories of the [SparkFun GNSS Combo Breakout - ZED-F9P, NEO-D9S repository](https://github.com/sparkfun/SparkFun_GNSS_Combo_Breakout-ZED-F9P_NEO-D9S).

<!-- ### :material-source-pull:&nbsp;Submit a Design Enhancement -->
### Submit a Design Enhancement

1. With a GitHub account, [fork this repository](https://github.com/sparkfun/SparkFun_GNSS_Combo_Breakout-ZED-F9P_NEO-D9S/fork).
2. Add your design augmentation(s)
3. File a pull request with your changes, and enjoy making the ~~words~~ ~~worlds~~ world a better place.
	1. Once received, the engineer in charge of the original design will automatically be notified.
	2. We will review your suggested improvement(s) to verify that they are within our board design standards and meet our product design requirements.
	3. If approved, we will flag these changes for our next board revision. Congrats! 🍻

		!!! info
			Even if your suggestion is accepted, these changes may not be immediately available for purchase. We may have to cycle through our current product inventory first.

## Contributors&nbsp;:clap:
Let's provide some recognition to the contributors for this project!

GitHub Contributors Image
<br>


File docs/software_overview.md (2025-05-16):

There are three key steps to be able to achieve centimeter positioning accuracy using the ZED-F9P NEO-D9S Combo Breakout:

* Register with u-blox Thingstream and sign up for a PointPerfect L-band plan (data stream)
* Configure the NEO-D9S to receive the u-blox PointPerfect correction data stream
* Configure the ZED-F9P with encryption key(s) so it can decrypt and use the correction data

By default, the Combo Breakout is configured such that the correction data is passed from the NEO to the ZED using the UART2 interface.
However, it is also possible to read the correction data from the NEO and push (write) it to the ZED using I<sup>2</sup>C.

## Thingstream and PointPerfect

[Thingstream](https://www.u-blox.com/en/product/thingstream) is u-blox service delivery platform for IoT Communication-as-a-Service, IoT Security-as-a-Service and IoT Location-as-a-Service.

[PointPerfect](https://www.u-blox.com/sites/default/files/PointPerfect_ProductSummary_UBX-21024758.pdf) is u-blox GNSS augmentation service which is designed to provide high-precision GNSS corrections to suitable receivers to provide decimeter-level location accuracy.

!!! warning
    u-blox provides products and services to "B2B Customers". Only business customers are eligible to register for a Thingstream (PointPerfect) account. You may be required to demonstrate that the use of the combo breakout is in relation to your trade, business, craft or profession. u-blox products and services are not intended for individual consumer use. Please check the [u-blox Service Terms](https://cdn.sparkfun.com/assets/2/5/a/4/f/Service_Terms.pdf) before purchasing hardware.

PointPerfect data is delivered through Thingstream. The first step is to [register with Thingstream](https://portal.thingstream.io/register) and then request an L-Band plan:

<figure markdown>
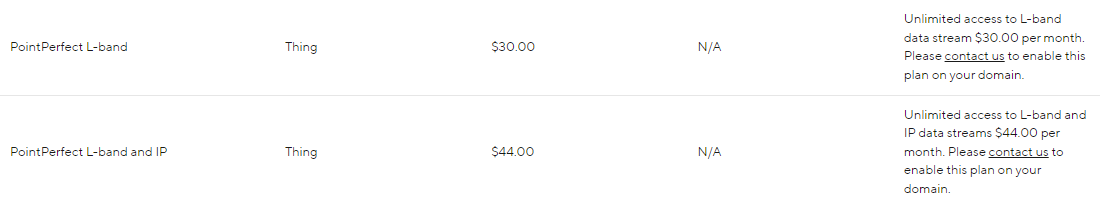
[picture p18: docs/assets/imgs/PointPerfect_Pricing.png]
PointPerfect Pricing

<figcaption markdown>
PointPerfect pricing (correct at Sept. 14th 2022).
</figcaption>
</figure>

You can find the current pricing on [u-blox portal](https://portal.thingstream.io/pricing). Select **IoT Location-as-a-Service** and then **PointPerfect**.

You may need to [contact u-blox](mailto:support@thingstream.io) first, to enable the option to purchase an L-Band plan through your Thingstream account.

The **PointPerfect L-band** plan provides unlimited access to the L-band satellite correction data stream (via the NEO-D9S).

If you have an internet connection, you can also receive PointPerfect corrections via IP (MQTT). The **PointPerfect L-band and IP** plan may be a better choice if
you think you may want to receive correction data via both satellite and Internet.

Once L-band permissions are enabled on your Thingstream account, you will be able to add a new L-band Location Thing and view its credentials:

* [Login to Thingstream](https://portal.thingstream.io/)
* Select **Location Services** and then **Location Things**
* The **Add Location Thing** button (top right) will allow you to select and activate an L-Band plan
* Once your L-band plan is active, you will be able to monitor your **Activity** and view your **Credentials** via the appropriate tabs

u-blox have written a [comprehensive application note](https://www.u-blox.com/sites/default/files/documents/NEO-D9S_ZED-F9_Config_SPARTN_AppNote_UBX-22008160.pdf) which
describes in detail: the configuration of both NEO and ZED; and how to interpret the expiry date for the L-band encryption keys.

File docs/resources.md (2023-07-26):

# Resources

For more resources related to the SparkFun u-blox ZED-F9P NEO-D9S Combo Breakout, check out the links listed here: 

* [Schematic](assets/board_files/SparkFun_GNSS_Combo_Breakout-ZED-F9P_NEO-D9S_Schematic.pdf) (PDF)
* [Eagle Files](assets/board_files/ZED-F9P_NEO-D9S_Combo_x02.zip) (ZIP)
* [Board Dimensions](assets/board_files/SparkFun_GNSS_Combo_Breakout-ZED-F9P_NEO-D9S_Dimensions.png) (PNG)
* [SparkFun u-blox GNSS Arduino Library](https://github.com/sparkfun/SparkFun_u-blox_GNSS_v3)
    * [Example: L-Band correction with correction data push via I<sup>2</sup>C](https://github.com/sparkfun/SparkFun_u-blox_GNSS_v3/tree/main/examples/NEO-D9S_and_NEO-D9C/Example2_LBand_Corrections_with_NEO-D9S). The I<sup>2</sup>C push is not necessary on the combo breakout. The correction data will be transferred automatically via UART2.
    * [Example: L-Band correction with key retrieval via MQTT](https://github.com/sparkfun/SparkFun_u-blox_GNSS_v3/tree/main/examples/NEO-D9S_and_NEO-D9C/Example6_PMP_with_L-Band_Keys_via_MQTT)

u-blox resources: 

* [NEO-D9S and ZED-F9 configuration - SPARTN L-band correction data reception](https://www.u-blox.com/sites/default/files/documents/NEO-D9S_ZED-F9_Config_SPARTN_AppNote_UBX-22008160.pdf)
* [u-blox u-center - GNSS evaluation software for Windows](https://www.u-blox.com/en/product/u-center)
* [PointPerfect GNSS augmentation service](https://www.u-blox.com/en/product/pointperfect)
* [PointPerfect Product Summary](https://www.u-blox.com/sites/default/files/PointPerfect_ProductSummary_UBX-21024758.pdf)
* [PointPerfect Service Description](https://developer.thingstream.io/guides/location-services/pointperfect-service-description)
* [PointPerfect Service Coverage](https://developer.thingstream.io/guides/location-services/pointperfect-service-description#h.jv0o1vz2wkn3)
* [Thingstream IoT service delivery platform](https://www.u-blox.com/en/product/thingstream)
* [Thingstream Login](https://portal.thingstream.io/)
* [Thingstream Registration](https://portal.thingstream.io/register)

Forums: 

* [SparkFun General Forums](https://forum.sparkfun.com/index.php)
* [SparkFun GPS Forums](https://forum.sparkfun.com/viewforum.php?f=116)

Check out other [tutorials related to GPS and GNSS](https://learn.sparkfun.com/tutorials/tags/gps):

<table style="border-style:none">
    <tr>
        <td style="vertical-align: text-top;" width="264px">
            <a href="https://learn.sparkfun.com/tutorials/sparkfun-rtk-facet-l-band-hookup-guide">
            
            <h3 style="vertical-align: left">SparkFun RTK L-Band Hookup Guide
            </h3></a>
        </td>
        <td style="vertical-align: text-top;" width="264px">
            <div style="text-align: center"><a href="https://learn.sparkfun.com/tutorials/getting-started-with-u-center-for-u-blox">
            </div>
            <h3 style="text-align: left">Getting Started with U-Center for u-blox
            </h3></a>
        </td>
        <td style="vertical-align: text-top;" width="264px">
            <div style="text-align: center"><a href="https://learn.sparkfun.com/tutorials/gps-rtk2-hookup-guide">
            </div>
            <h3 style="text-align: left">GPS-RTK2 Hookup Guide
            </h3></a>
        </td>
        <td style="vertical-align: text-top;" width="264px">
            <a href="https://learn.sparkfun.com/tutorials/sparkfun-gps-breakout-zoe-m8q-and-sam-m8q-hookup-guide">
            
            <h3 style="text-align: left">SparkFun GPS Breakout (ZOE-M8Q and SAM-M8Q) Hookup Guide
            </h3></a>
        </td>
    </tr>
</table>

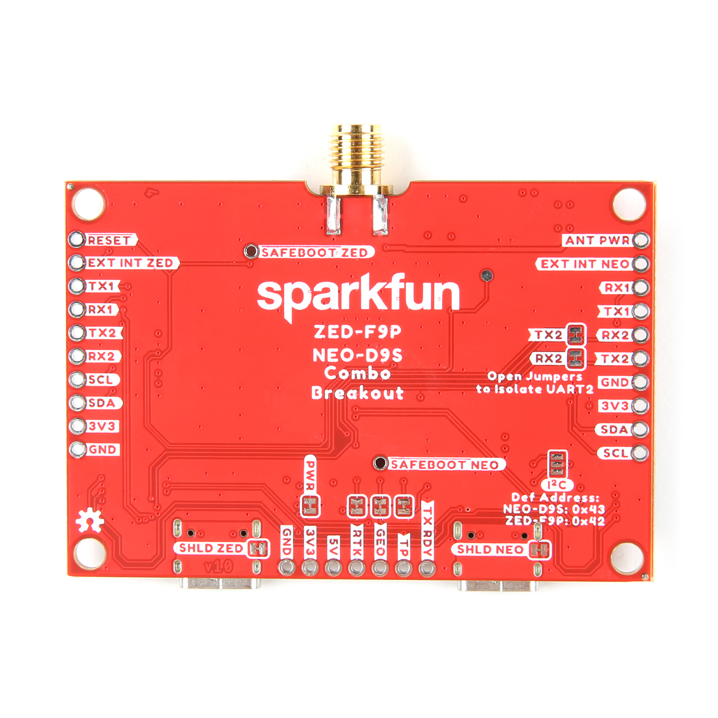
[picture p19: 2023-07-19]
docs/assets/imgs/22560-GPS-SparkFun-u-blox-ZED-F9P-NEO-D9S-Combo-Breakout-03-HIGH-RES .jpg

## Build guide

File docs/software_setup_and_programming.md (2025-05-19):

!!! attention
    If this is your first time using Arduino, please review our tutorial on [installing the Arduino IDE](https://learn.sparkfun.com/tutorials/installing-arduino-ide). If you have not previously installed an Arduino library, please check out our [installation guide](https://learn.sparkfun.com/tutorials/installing-an-arduino-library).

SparkFun has an extensive library for its GNSS boards. You can obtain this library through the Arduino Library Manager by searching for "GNSS v3" and installing the latest version. If you prefer downloading libraries manually, you can grab them from the GitHub Repository.

<center>
<a class="md-button md-button--primary" href="https://github.com/sparkfun/SparkFun_u-blox_GNSS_v3/archive/refs/heads/main.zip" target="_blank" rel="noopener">u-blox GNSS Arduino Library v3</a>
</center>

## NEO-D9S Configuration

The first step is to declare the **`SFE_UBLOX_GNSS`** object. Like most Arduino sketches, this is done at a global scope (after the include file declaration), not within the ```setup()``` or ```loop()``` functions. 

```C++
#include <SparkFun_u-blox_GNSS_v3.h> //http://librarymanager/All#SparkFun_u-blox_GNSS_v3
SFE_UBLOX_GNSS myLBand; // NEO-D9S
```

Within ```setup()``` we then need to start (initialize) communiation with the NEO-D9S.
The NEO-D9S has a default I<sup>2</sup>C address of 0x43 and so we need to provide that when calling the ```begin``` method:

```C++
  Wire.begin(); //Start I2C

  while (myLBand.begin(Wire, 0x43) == false) //Connect to the u-blox NEO-D9S using Wire port. The D9S default I2C address is 0x43 (not 0x42)
  {
    Serial.println(F("u-blox NEO-D9S not detected at default I2C address. Please check wiring."));
    delay(2000);
  }
  Serial.println(F("u-blox NEO-D9S connected"));

```

The NEO-D9S needs to be configured so it can receive the PointPerfect correction stream. The configuration items are: 

| Configuration item | Default value |
| :--- | :---- |
| CFG-PMP-CENTER_FREQUENCY | 1539812500 Hz |
| CFG-PMP-SEARCH_WINDOW | 2200 Hz |
| CFG-PMP-USE_SERVICE_ID | 1 (true)|
| CFG-PMP-SERVICE_ID | 50821 |
| CFG-PMP-DATA_RATE | 2400 (B2400) bps |
| CFG-PMP-USE_DESCRAMBLER | 1 (true) |
| CFG-PMP-DESCRAMBLER_INIT | 23560 |
| CFG-PMP-USE_PRESCRAMBLING | 0 (false) |
| CFG-PMP-UNIQUE_WORD | 0xe15ae893e15ae893 |

The centre frequency varies depending on which satellite is broadcasting corrections for your geographical area.

The up-to-date frequencies are distributed via the MQTT **/pp/frequencies/Lb** topic. At the time of writing, they are (in MHz):

```C++
{
  "frequencies": {
    "us": {
      "current": {
        "value": "1556.29"
      }
    }
  }
}
```

We can add that to the code as follows:

```C++
const uint32_t myLBandFreq = 1556290000; // Uncomment this line to use the US SPARTN 1.8 service
```

The code to configure the NEO-D9S is as follows. Note that the **`UBLOX_CFG_PMP_USE_SERVICE_ID`**, **`UBLOX_CFG_PMP_SERVICE_ID`** and **`UBLOX_CFG_PMP_DESCRAMBLER_INIT`**
also need to be changed.

```C++
  uint8_t ok = myLBand.setVal(UBLOX_CFG_PMP_CENTER_FREQUENCY,  myLBandFreq); // Default 1539812500 Hz
  if (ok) ok = myLBand.setVal(UBLOX_CFG_PMP_SEARCH_WINDOW,     2200);        // Default 2200 Hz
  if (ok) ok = myLBand.setVal(UBLOX_CFG_PMP_USE_SERVICE_ID,    0);           // Default 1 
  if (ok) ok = myLBand.setVal(UBLOX_CFG_PMP_SERVICE_ID,        21845);       // Default 50821
  if (ok) ok = myLBand.setVal(UBLOX_CFG_PMP_DATA_RATE,         2400);        // Default 2400 bps
  if (ok) ok = myLBand.setVal(UBLOX_CFG_PMP_USE_DESCRAMBLER,   1);           // Default 1
  if (ok) ok = myLBand.setVal(UBLOX_CFG_PMP_DESCRAMBLER_INIT,  26969);       // Default 23560
  if (ok) ok = myLBand.setVal(UBLOX_CFG_PMP_USE_PRESCRAMBLING, 0);           // Default 0
  if (ok) ok = myLBand.setVal(UBLOX_CFG_PMP_UNIQUE_WORD,       16238547128276412563ull); // 0xE15AE893E15AE893
```

Finally, we need to ensure that the UART2 port is set correctly. We need to:

* Change the baud rate to 38400 - to match the ZED-F9P's baud rate
* Ensure that the **UBX** protocol is enabled for output on UART2
* Enable the **RXM PMP** message on UART2
    * The **RXM PMP** message contains the **SPARTN** correction data in **UBX** format
* Perform a restart (software reset) so that the NEO-D9S starts using the new configuration items

```C++
  if (ok) ok = myLBand.setVal(UBLOX_CFG_UART2_BAUDRATE,           38400); // match baudrate with ZED default
  if (ok) ok = myLBand.setVal(UBLOX_CFG_UART2OUTPROT_UBX,         1);     // Enable UBX output on UART2
  if (ok) ok = myLBand.setVal(UBLOX_CFG_MSGOUT_UBX_RXM_PMP_UART2, 1);     // Output UBX-RXM-PMP on UART2
  
  Serial.print(F("L-Band configuration: "));
  if (ok)
    Serial.println(F("OK"));
  else
    Serial.println(F("NOT OK!"));

  myLBand.softwareResetGNSSOnly(); // Do a restart
```

Once the NEO-D9S has aquired the signal from the satellite, it will start outputting **PMP** correction messages to the ZED-F9P on UART2.

## ZED-F9P Configuration

We need to declare a second **`SFE_UBLOX_GNSS`** object for the ZED-F9P. Again, this is done at a global scope (after the include file declaration), not within the ```setup()``` or ```loop()``` functions. 

```C++
SFE_UBLOX_GNSS myGNSS; // ZED-F9P
```

Within ```setup()``` we need to start (initialize) communiation with the ZED-F9P:

```C++
  while (myGNSS.begin() == false) //Connect to the u-blox module using Wire port and the default I2C address (0x42)
  {
    Serial.println(F("u-blox GNSS module not detected at default I2C address. Please check wiring."));
    delay(2000);
  }
  Serial.println(F("u-blox GNSS module connected"));
```

We then need to:

* Make sure the ZED-F9P's UART2 port is configured to accept the PMP correction data
* Tell the ZED-F9P to use FIXED carrier solutions when possible (this is the default setting)
* Tell the ZED-F9P to accept L-band PMP as a correction source

```C++
          ok = myGNSS.setI2CInput(COM_TYPE_UBX | COM_TYPE_NMEA | COM_TYPE_SPARTN); //Be sure SPARTN input is enabled
  if (ok) ok = myGNSS.setDGNSSConfiguration(SFE_UBLOX_DGNSS_MODE_FIXED); // Set the differential mode - ambiguities are fixed whenever possible
  if (ok) ok = myGNSS.setVal8(UBLOX_CFG_SPARTN_USE_SOURCE, 1); // use LBAND PMP message
```

The final piece of the puzzle is to provide the ZED-F9P with the keys it needs to decrypt the encrypted SPARTN (PMP) corrections.

The ZED-F9P can hold two dynamic keys: the current key; and the next key. We also need to tell it when each key is valid from, so it knows when to switch to the next key.

You can find the current and next keys in the **`Location Services \ Location Things \ Thing Details \ Credentials`** tab in Thingstream:

<figure markdown>
L-band Dynamic Keys
<figcaption markdown>
PointPerfect L-band dynamic keys.
</figcaption>
</figure>

The ZED-F9P actually needs to know when the keys are valid **from**, rather than when they expire. Each key is walid for four weeks, so we need to work backwards 4 weeks from the expiry date.

The current key expires at midnight (UTC) at the end of Friday September 23rd. This means it became valid 4 weeks earlier at midnight (UTC) on August 27th:

<figure markdown>
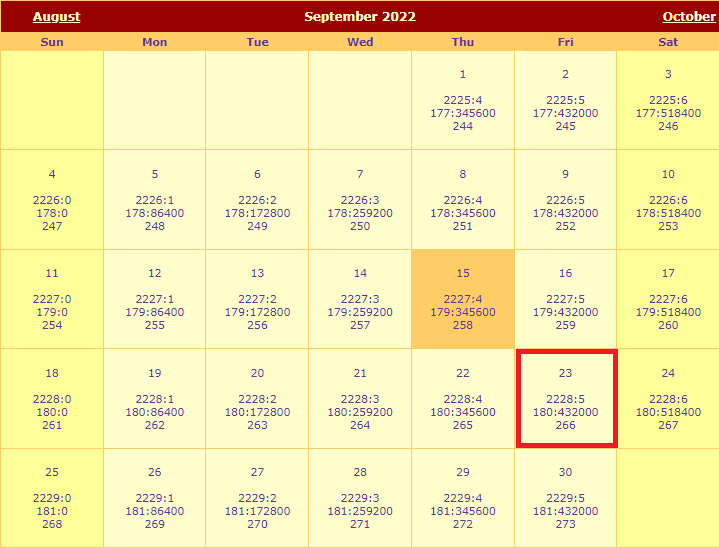
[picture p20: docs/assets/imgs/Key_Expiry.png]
Dynamic Key expiry

<figcaption markdown>
Dynamic Key expiry.
</figcaption>
</figure>

<figure markdown>
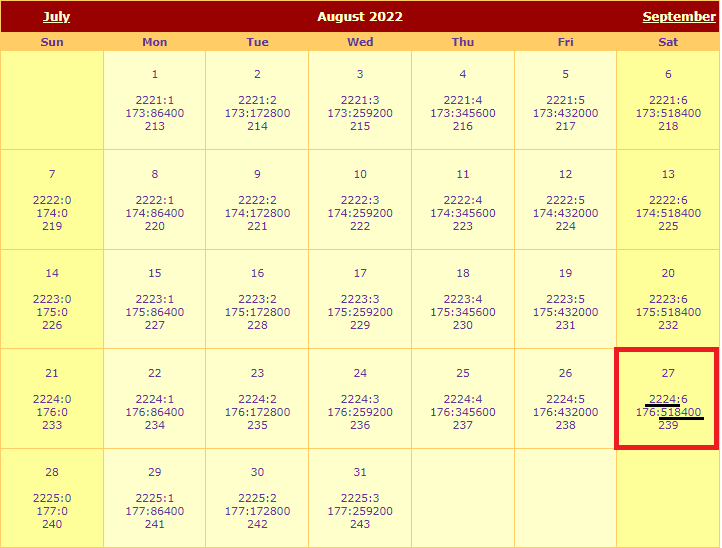
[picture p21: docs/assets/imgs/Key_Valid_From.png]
Dynamic Key valid from

<figcaption markdown>
Dynamic Key: Expiry and Valid From dates.
</figcaption>
</figure>

Using the website recommended in the u-blox Application Note:

**http://navigationservices.agi.com/GNSSWeb**

we can see that the key became valid during GPS week **2224**, at time-of-week **518400**.

We can use the Arduino Library **`setDynamicSPARTNKey`** method to configure a single key:

```C++
  if (ok) ok = myGNSS.setDynamicSPARTNKey(16, 2224, 518400, "500--------------------------177");

  Serial.print(F("GNSS: configuration "));
  if (ok)
    Serial.println(F("OK"));
  else
    Serial.println(F("NOT OK!"));
```

Alternately, we can set both the current key and the next key together using **`setDynamicSPARTNKeys`**. The next key becomes valid during GPS week **2228**:

```C++
  if (ok) ok = myGNSS.setDynamicSPARTNKeys(16, 2224, 518400, "500--------------------------177", 16, 2228, 518400, "582--------------------------a7d");
```

The keys can also be retrieved using MQTT. We have an [Arduino Library example](https://github.com/sparkfun/SparkFun_u-blox_GNSS_v3/tree/main/examples/NEO-D9S_and_NEO-D9C/Example6_PMP_with_L-Band_Keys_via_MQTT)
which shows how to retrieve the keys from the L-band + IP key distribution topic **/pp/ubx/0236/Lb** . That topic provides the keys in UBX (binary) format, ready to be pushed to the ZED.

The keys are also available in human-readable JSON format from the MQTT topic **/pp/key/Lb** . But note that that topic provides the **valid from** in Unix epoch format,
in milliseconds, excluding the 18 leap seconds since GPS time started!

```C++
{
  "dynamickeys": {
    "current": {
      "start": "1661558382000",
      "duration": "2419199999",
      "value": "500--------------------------177"
    },
    "next": {
      "start": "1663977582000",
      "duration": "2419199999",
      "value": "582--------------------------a7d"
    }
  }
}
```

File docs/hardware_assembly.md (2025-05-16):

At a minimum, you will need to attach an external antenna to the SparkFun GNSS Combo Breakout ZED-F9P NEO-D9S, supply 3.3V power, and connect to one of the board's peripherals.

### Attaching an External Antenna

Plug in one of our patch antennas with SMA connector to the GPS board. Secure the connection using the hex nut until it is finger-tight.

<figure markdown>
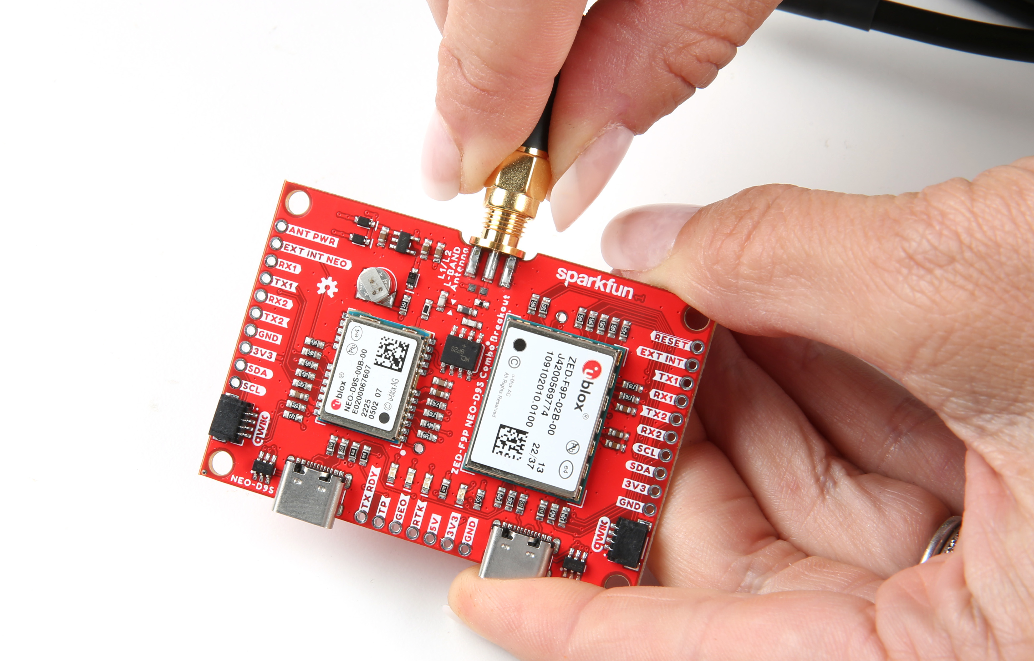
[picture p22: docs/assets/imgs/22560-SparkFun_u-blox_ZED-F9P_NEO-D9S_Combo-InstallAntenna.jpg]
Finger Tightening the SMA GPS Antenna to the SparkFun GNSS Combo Breakout ZED-F9P NEO-D9S Breakout

<figcaption markdown>
Finger Tightening the SMA GPS Antenna to the SparkFun GNSS Combo Breakout ZED-F9P NEO-D9S Breakout.
</figcaption>
</figure>

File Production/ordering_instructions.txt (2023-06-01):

panel size, 109x142mm
PCB thickness, 1.6mm
number of layers, 4
controlled impedance, JLC7628
soldermask color, Red
silkscreen color, White
oz copper, 1oz
finish, HASL lead free
stencils, top
pcs per panel, 4
min trace width, 0.1524mm / 0.0060in
min drill size, 0.3048mm / 0.0120in
filename to layer stackup 1/2/3/4: GTL, GL2, GL3, GBL

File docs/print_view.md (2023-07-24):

---
hide:
  - navigation
  - toc
icon: fontawesome/solid/scroll
---

# Introduction
--8<-- "./docs/introduction.md"

# Hardware Overview
--8<-- "./docs/hardware_overview.md"

# Hardware Assembly
--8<-- "./docs/hardware_assembly.md"

# Software Overview
--8<-- "./software_overview.md"

# Software Setup
--8<-- "./software_setup_and_programming.md"

# Troubleshooting
--8<-- "./docs/troubleshooting.md"

# Resources:
--8<-- "./docs/resources.md"

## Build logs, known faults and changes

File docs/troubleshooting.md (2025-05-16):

!!! note
    <span class="glyphicon glyphicon-question-sign" aria-hidden="true"></span>
        <strong> Not working as expected and need help? </strong> <br /><br />

    If you need technical assistance and more information on a product that is not working as you expected, we recommend heading on over to the <a href="https://www.sparkfun.com/technical_assistance">SparkFun Technical Assistance</a> page for some initial troubleshooting. <br /><br />

    <div style="text-align: center"><a href="https://www.sparkfun.com/technical_assistance" target="sfe_technical_assistance" class="md-button">SparkFun Technical Assistance Page</a></div>

    If you don't find what you need there, the <a href="https://forum.sparkfun.com/index.php">SparkFun Forums</a> are a great place to find and ask for help. Make sure you check out the <a href="https://forum.sparkfun.com/viewforum.php?f=116">GPS Forums</a>. 
    
    Note that if this is your first visit to the forums, you'll need to <a href="https://forum.sparkfun.com/ucp.php?mode=register">create a Forum Account</a> to search product forums and post questions.<br /><br />

    <div style="text-align: center"><a href="https://forum.sparkfun.com/ucp.php?mode=register" class="md-button">Create New Forum Account</a>&nbsp;&nbsp;&nbsp;<a href="https://forum.sparkfun.com/index.php" class="md-button md-button--primary">Log Into SparkFun Forums</a></div>

## Tips and Tricks

!!! attention
    u-blox provides products and services to "B2B Customers". Only business customers are eligible to register for a Thingstream (PointPerfect) account. You may be required to demonstrate that the use of the combo breakout is in relation to your trade, business, craft or profession. u-blox products and services are not intended for individual consumer use.

## PointPerfect L-band Reception

In order to receive the u-blox PointPerfect correction data, you will: need a suitable antenna; need to be located within contiguous USA; and have a clear view of the sky to the South.

### SparkFun GNSS Multi-Band L1/L2 Surveying Antenna - TOP106

We have been successful using the [SparkFun GNSS Multi-Band L1/L2 Surveying Antenna (TNC) - TOP106 (GPS-17751)](https://www.sparkfun.com/products/17751) antenna to receive
PointPerfect correction data in the USA.

### PointPerfect Coverage

The PointPerfect GNSS augmentation service is available on a continental scale with seamless coverage in the contiguous USA, including up to 12 nautical miles  (~ 22 km) off coastlines.

<figure markdown>
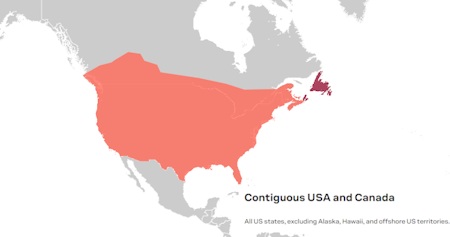
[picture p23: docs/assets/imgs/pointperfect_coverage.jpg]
PointPerfect Service Coverage

<figcaption markdown>
PointPerfect Service Coverage.
</figcaption>
</figure>

### PointPerfect Satellite Broadcast

PointPerfect augmentation data is broadcast from a satellite covering the contiguous USA. The satellite is in geostationary orbits over the equator - the same as for satellite television broadcasts. It is essential that your antenna has an unobstructed view of the sky, especially to the South where the satellite is positioned.

Depending on your latitude, the satellite for your area could be low in the sky. You need to ensure that trees, buildings etc. are not blocking the signal.

## Don't see what you need?
The use cases for this Combo Board are too numerous and complex to cover all potential issues. If you are having issues that we haven't covered here, please refer to the <a href="https://forum.sparkfun.com/index.php">SparkFun Forums</a> for help. If this is your first visit, you'll need to <a href="https://forum.sparkfun.com/ucp.php?mode=register">create a Forum Account</a> to search product forums and post questions.<br /><br />

<div style="text-align: center"><a href="https://forum.sparkfun.com/ucp.php?mode=register" class="md-button">Create New Forum Account</a>&nbsp;&nbsp;&nbsp;<a href="https://forum.sparkfun.com/index.php" class="md-button md-button--primary">Log Into SparkFun Forums</a> </div>

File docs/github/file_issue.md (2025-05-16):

## Need Assistance?

<!-- Technical Assistance Box -->
!!! warning "Need Help?"
	If you need technical assistance or more information on a product that is not working as you expected, we recommend heading on over to the [SparkFun Technical Assistance](https://www.sparkfun.com/technical_assistance) page for some initial troubleshooting. This **Submit Issues** page is not where users should seek assistance.

	<center>
	[SparkFun Technical Assistance Page](https://www.sparkfun.com/technical_assistance){ .md-button .md-button--primary }
	</center>

	If you can't find what you need there, the [SparkFun Forums](https://forum.sparkfun.com) is a great place to search the product forums and ask questions.

	!!! info "Account Registration Required"
		For your first visit to our forum, you'll need to create a [Forum Account](https://forum.sparkfun.com/ucp.php?mode=register) to post questions.

## Did we make a mistake?
Spot something wrong? Please let us know. 

### Discrepancies in the Documentation
All of our documentation can be modified by you! Please help us make it better.

- The documentation files for these pages are contained in the [`docs` folder](https://github.com/sparkfun/SparkFun_GNSS_Combo_Breakout-ZED-F9P_NEO-D9S/tree/main/docs) of the [SparkFun GNSS Combo Breakout - ZED-F9P, NEO-D9S repository](https://github.com/sparkfun/SparkFun_GNSS_Combo_Breakout-ZED-F9P_NEO-D9S).

#### 🔍 Spot something wrong?
If a section of the documentation is incorrect, please [open an issue](https://github.com/sparkfun/SparkFun_GNSS_Combo_Breakout-ZED-F9P_NEO-D9S/issues) and let us know.

#### Do you have a suggested correction?

1. With a GitHub account, [fork this repository](https://github.com/sparkfun/SparkFun_GNSS_Combo_Breakout-ZED-F9P_NEO-D9S/fork).
2. Add your correction(s) or improvement(s) to the markdown file(s)
3. File a pull request with your changes, and enjoy making the ~~words~~ ~~worlds~~ world a better place.
	- Once received, the documentation specialist will automatically be notified.
	- We will review your suggested improvement(s) to make sure they are correct and fit within our documentation standards.

### Problems in the Hardware Design
All of our designs are open-source! Please help us make it better.

- Our board design files are contained in the `/Hardware` directories of the [SparkFun GNSS Combo Breakout - ZED-F9P, NEO-D9S repository](https://github.com/sparkfun/SparkFun_GNSS_Combo_Breakout-ZED-F9P_NEO-D9S).

#### Does something not make sense? 🤔
If part of the design is confusing, please [open an issue](https://github.com/sparkfun/SparkFun_GNSS_Combo_Breakout-ZED-F9P_NEO-D9S/issues) and let us know.

#### Did we forget to include an important function of the board? 🤦
If part of the board's functionality is missing, please [open an issue](https://github.com/sparkfun/SparkFun_GNSS_Combo_Breakout-ZED-F9P_NEO-D9S/issues) and file a feature request.

!!! tip "Design Considerations"
	Please keep in mind that we may intentionally exclude certain functions of the board to meet our product design requirements.

	- *For example, our Qwiic Micro boards are intended to fit on a small board layout and only use I^2^C communication; therefore, we may not have the SPI and interrupt pins available for users.*

#### Do you wish to contribute directly to improving the board design?

1. With a GitHub account, [fork this repository](https://github.com/sparkfun/SparkFun_GNSS_Combo_Breakout-ZED-F9P_NEO-D9S/fork).
2. Add your design augmentation(s)
3. File a pull request with your changes, and enjoy making the ~~words~~ ~~worlds~~ world a better place.
	1. Once received, the engineer in charge of the original design will automatically be notified.
	2. We will review your suggested improvement(s) to verify that they are within our board design standards and meet our product design requirements.
	3. If approved, we will flag these changes for our next board revision. Congrats! 🍻

		!!! info
			Even if your suggestion is accepted, these changes may not be immediately available for purchase. We may have to cycle through our current product inventory first.

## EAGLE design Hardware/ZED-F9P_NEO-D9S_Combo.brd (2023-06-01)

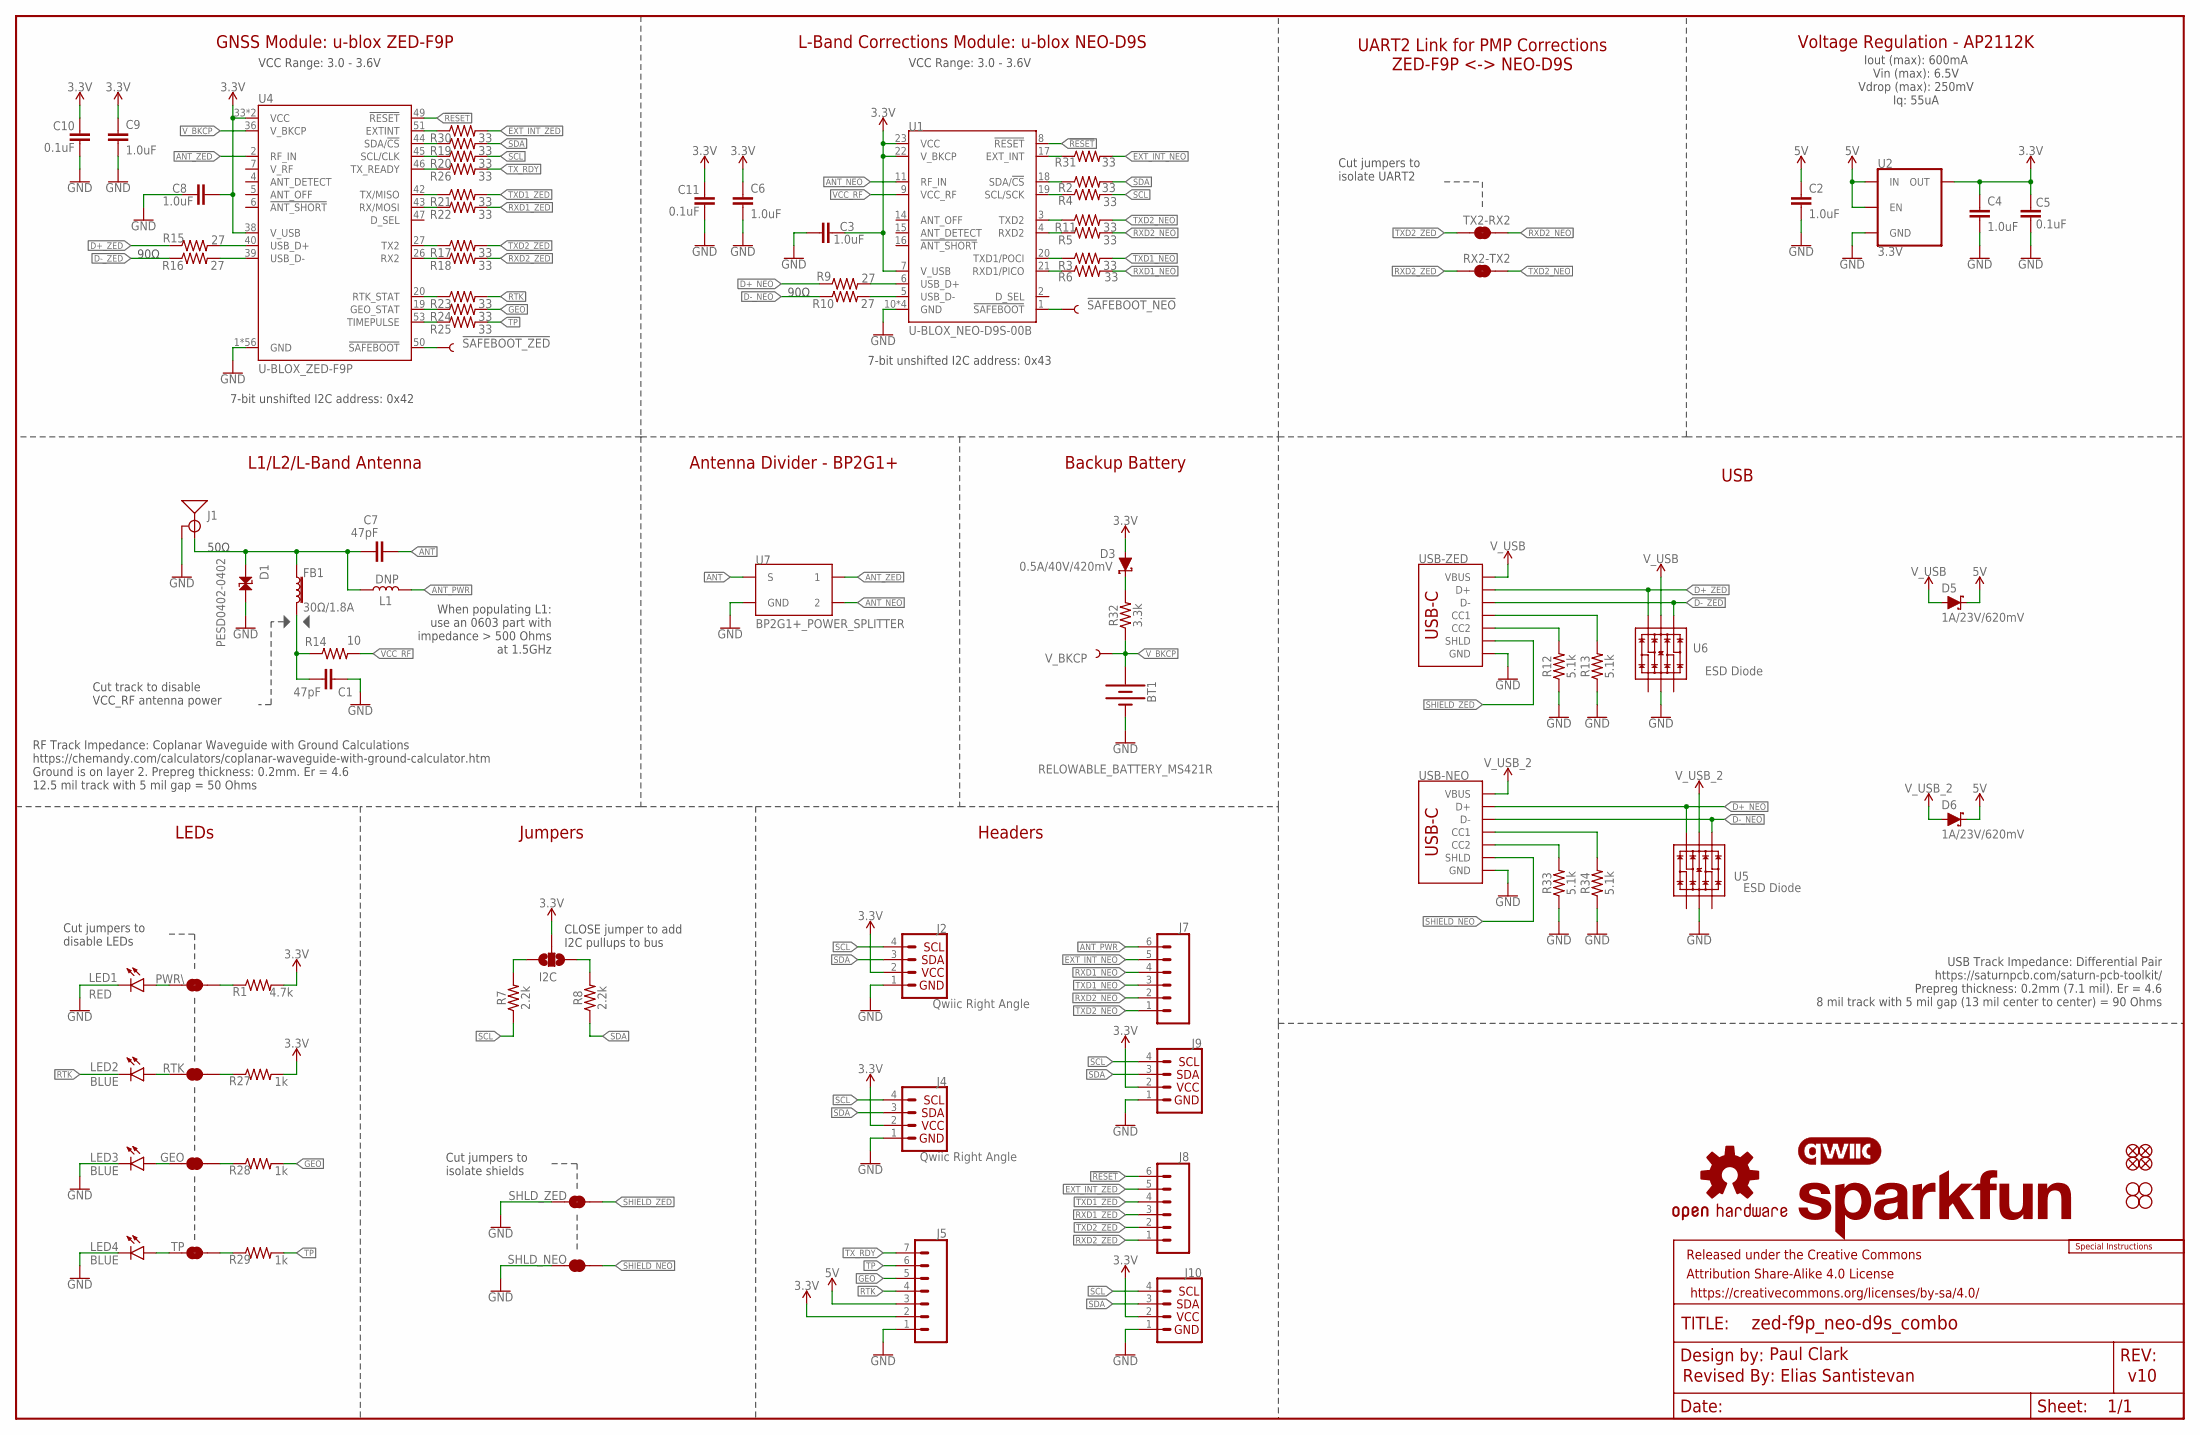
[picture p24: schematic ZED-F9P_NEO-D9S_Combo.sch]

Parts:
!SAFEBOOT_NEO!: TEST-POINTPOGO_PTH; 1X01_NO_SILK
!SAFEBOOT_ZED!: TEST-POINTPOGO_PTH; 1X01_NO_SILK
BT1: RELOWABLE_BATTERY_MS421R; MS421R_IV03E
C1, C7: 47pF; 0603
C2, C3, C4, C6, C8, C9: 1.0uF; 0603
C5, C10, C11: 0.1uF; 0603
D1: PESD0402-0402; 0402
D3: 0.5A/40V/420mV; SOD-323
D5, D6: 1A/23V/620mV; SOD-323
FB1: 30Ω/1.8A; 0603
FRAME2: FRAME-LEDGER; CREATIVE_COMMONS
GEO: JUMPER-SMT_2_NC_TRACE_SILK; SMT-JUMPER_2_NC_TRACE_SILK
I2C: JUMPER-SMT_3_NO_SILK; SMT-JUMPER_3_NO_SILK
J1: ANTENNA-SMA-GROUNDEDEDGE_SMA; SMA-EDGE
J2, J4: Qwiic Right Angle; JST04_1MM_RA
J5: CONN_07NO_SILK; 1X07_NO_SILK
J7, J8: CONN_06NO_SILK_NO_POP; 1X06_NO_SILK
J9, J10: I2C_STANDARD_NO_SILK; 1X04_NO_SILK
JP21, JP61, JP71, JP81: FIDUCIALUFIDUCIAL; MICRO-FIDUCIAL
JP31, JP41, JP91, JP101: STAND-OFF
L1: DNP; 0603_NO-CREAM
LED1: RED; LED-0603
LED2, LED3, LED4: BLUE; LED-0603
LOGO2: SFE_LOGO_NAME.1_INCH; SFE_LOGO_NAME_.1
LOGO3: QWIIC_LOGO_5MM; QWIIC_5MM
LOGO4: OSHW-LOGOS; OSHW-LOGO-S
LOGO5: SPECIAL_INSTRUCTIONS-ORDERING; ORDERING_INSTRUCTIONS
PWR\: JUMPER-SMT_2_NC_TRACE_SILK; SMT-JUMPER_2_NC_TRACE_SILK
R1: 4.7k; 0603
R2, R3, R4, R5, R6, R11, R17, R18, R19, R20, R21, R22, R23, R24, R25, R26, R30, R31: 33; 0603
R7, R8: 2.2k; 0603
R9, R10, R15, R16: 27; 0603
R12, R13, R33, R34: 5.1k; 0603
R14: 10; 0603
R27, R28, R29: 1k; 0603
R32: 3.3k; 0603
RTK: JUMPER-SMT_2_NC_TRACE_SILK; SMT-JUMPER_2_NC_TRACE_SILK
RX2-TX2: JUMPER-SMT_2_NC_TRACE_SILK; SMT-JUMPER_2_NC_TRACE_SILK
SHLD_NEO: JUMPER-SMT_2_NC_TRACE_SILK; SMT-JUMPER_2_NC_TRACE_SILK
SHLD_ZED: JUMPER-SMT_2_NC_TRACE_SILK; SMT-JUMPER_2_NC_TRACE_SILK
TP: JUMPER-SMT_2_NC_TRACE_SILK; SMT-JUMPER_2_NC_TRACE_SILK
TX2-RX2: JUMPER-SMT_2_NC_TRACE_SILK; SMT-JUMPER_2_NC_TRACE_SILK
U1: U-BLOX_NEO-D9S-00B; NEO-M9N/M8T/M8U/D9S
U2: 3.3V; SOT23-5
U4: U-BLOX_ZED-F9P; ZED-F9P
U5, U6: ESD Diode; SOT-23-6
U7: BP2G1+_POWER_SPLITTER; XX21
USB-NEO: USB Female Type C Connector; USB-C-16P_4LAYER-PADS
USB-ZED: USB Female Type C Connector; USB-C-16P_4LAYER-PADS
V_BKCP: TEST-POINT3X5; PAD.03X.05

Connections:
3.3V: C3.1, C4.1, C5.2, C6.1, C8.2, C9.1, C10.2, C11.2, D3.A, I2C.2, J2.2, J4.2, J5.2, J9.2, J10.2, R1.2, R27.2, U1.7 (V_USB), U1.22 (V_BKCP), U1.23 (VCC), U2.5 (OUT), U4.33 (VCC), U4.34 (VCC), U4.38 (V_USB)
5V: C2.1, D5.C, D6.C, J5.3, U2.1 (IN), U2.3 (EN)
!RESET!: J8.6, U1.8 (!RESET!), U4.49 (!RESET!)
!SAFEBOOT_NEO!: !SAFEBOOT_NEO!.1, U1.1 (!SAFEBOOT!)
!SAFEBOOT_ZED!: !SAFEBOOT_ZED!.1, U4.50 (!SAFEBOOT!)
ANT: C7.2, U7.2 (S)
ANT_NEO: U1.11 (RF_IN), U7.5 (2)
ANT_PWR: J7.6, L1.2
ANT_VCC: C1.1, FB1.2, R14.1
ANT_ZED: U4.2 (RF_IN), U7.8 (1)
D+_NEO: R9.1, U5.6 (IO4), USB-NEO.A6 (D+), USB-NEO.B6 (D+)
D+_ZED: R15.1, U6.6 (IO4), USB-ZED.A6 (D+), USB-ZED.B6 (D+)
D-_NEO: R10.1, U5.4 (IO3), USB-NEO.A7 (D-), USB-NEO.B7 (D-)
D-_ZED: R16.1, U6.4 (IO3), USB-ZED.A7 (D-), USB-ZED.B7 (D-)
EXT_INT_NEO: J7.5, R31.2
EXT_INT_ZED: J8.5, R30.2
GEO: J5.5, R24.2, R28.2
GND: BT1.-, C1.2, C2.2, C3.2, C4.2, C5.1, C6.2, C8.1, C9.2, C10.1, C11.1, D1.2, J1.GND@0 (GND), J1.GND@1 (GND), J1.GND@2 (GND), J1.GND@3 (GND), J2.1, J4.1, J5.1, J9.1, J10.1, LED1.C, LED3.C, LED4.C, R12.1, R13.1, R33.1, R34.1, SHLD_NEO.1, SHLD_ZED.1, U1.10 (GND), U1.12 (GND), U1.13 (GND), U1.24 (GND), U2.2 (GND), U4.1 (GND), U4.3 (GND), U4.12 (GND), U4.14 (GND), U4.32 (GND), U4.37 (GND), U4.41 (GND), U4.48 (GND), U4.55 (GND), U4.56 (GND), U4.57 (GND), U4.58 (GND), U4.59 (GND), U4.60 (GND), U4.61 (GND), U4.62 (GND), U4.63 (GND), U4.64 (GND), U4.65 (GND), U4.66 (GND), U4.67 (GND), U4.68 (GND), U4.69 (GND), U4.70 (GND), U4.71 (GND), U4.72 (GND), U4.73 (GND), U4.74 (GND), U4.75 (GND), U4.76 (GND), U4.77 (GND), U4.78 (GND), U4.79 (GND), U4.80 (GND), U4.81 (GND), U4.82 (GND), U4.83 (GND), U4.84 (GND), U4.85 (GND), U4.86 (GND), U4.87 (GND), U4.88 (GND), U4.89 (GND), U4.90 (GND), U4.91 (GND), U4.92 (GND), U4.93 (GND), U4.94 (GND), U4.95 (GND), U4.96 (GND), U4.97 (GND), U4.98 (GND), U4.99 (GND), U4.100 (GND), U4.101 (GND), U4.102 (GND), U5.2 (VSS), U6.2 (VSS), U7.1 (GND), U7.3 (GND), U7.4 (GND), U7.6 (GND), U7.7 (GND), USB-NEO.GND, USB-NEO.GND2 (GND), USB-ZED.GND, USB-ZED.GND2 (GND)
unnamed: PWR\.2, R1.1
unnamed: R3.1, U1.20 (TXD1/POCI)
unnamed: R2.1, U1.18 (SDA/!CS!)
unnamed: R4.1, U1.19 (SCL/SCK)
unnamed: I2C.1, R8.2
unnamed: R6.1, U1.21 (RXD1/PICO)
unnamed: R12.2, USB-ZED.B5 (CC2)
unnamed: I2C.3, R7.2
unnamed: R13.2, USB-ZED.A5 (CC1)
unnamed: LED1.A, PWR\.1
unnamed: R9.2, U1.6 (USB_D+)
unnamed: R10.2, U1.5 (USB_D-)
unnamed: D3.C, R32.2
unnamed: R11.1, U1.3 (TXD2)
unnamed: R5.1, U1.4 (RXD2)
unnamed: R15.2, U4.40 (USB_D+)
unnamed: R16.2, U4.39 (USB_D-)
unnamed: R19.1, U4.44 (SDA/!CS!)
unnamed: R20.1, U4.45 (SCL/CLK)
unnamed: R21.1, U4.42 (TX/MISO)
unnamed: R22.1, U4.43 (RX/MOSI)
unnamed: R26.1, U4.46 (TX_READY)
unnamed: LED2.A, RTK.1
unnamed: R17.1, U4.27 (TX2)
unnamed: R18.1, U4.26 (RX2)
unnamed: GEO.1, LED3.A
unnamed: LED4.A, TP.1
unnamed: R27.1, RTK.2
unnamed: GEO.2, R28.1
unnamed: R29.1, TP.2
unnamed: R30.1, U4.51 (EXTINT)
unnamed: R31.1, U1.17 (EXT_INT)
unnamed: R33.2, USB-NEO.B5 (CC2)
unnamed: R34.2, USB-NEO.A5 (CC1)
unnamed: R23.1, U4.20 (RTK_STAT)
unnamed: R24.1, U4.19 (GEO_STAT)
unnamed: R25.1, U4.53 (TIMEPULSE)
RTK: J5.4, LED2.C, R23.2
RXD1_NEO: J7.4, R6.2
RXD1_ZED: J8.3, R22.2
RXD2_NEO: J7.2, R5.2, TX2-RX2.2
RXD2_ZED: J8.1, R18.2, RX2-TX2.1
SCL: J2.4, J4.4, J9.4, J10.4, R4.2, R7.1, R20.2
SDA: J2.3, J4.3, J9.3, J10.3, R2.2, R8.1, R19.2
SHIELD_NEO: SHLD_NEO.2, USB-NEO.SHLD1 (SHLD), USB-NEO.SHLD2 (SHLD), USB-NEO.SHLD3 (SHLD), USB-NEO.SHLD4 (SHLD)
SHIELD_ZED: SHLD_ZED.2, USB-ZED.SHLD1 (SHLD), USB-ZED.SHLD2 (SHLD), USB-ZED.SHLD3 (SHLD), USB-ZED.SHLD4 (SHLD)
SMA: C7.1, D1.1, FB1.1, J1.SIG (SIGNAL), L1.1
TP: J5.6, R25.2, R29.2
TXD1_NEO: J7.3, R3.2
TXD1_ZED: J8.4, R21.2
TXD2_NEO: J7.1, R11.2, RX2-TX2.2
TXD2_ZED: J8.2, R17.2, TX2-RX2.1
TX_RDY: J5.7, R26.2
VCC_RF: R14.2, U1.9 (VCC_RF)
V_BKCP: BT1.+, R32.1, U4.36 (V_BKCP), V_BKCP.1
V_USB: D5.A, U6.5 (VCC), USB-ZED.VBUS1 (VBUS), USB-ZED.VBUS2 (VBUS)
V_USB_2: D6.A, U5.5 (VCC), USB-NEO.VBUS1 (VBUS), USB-NEO.VBUS2 (VBUS)

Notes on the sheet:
v10
7-bit unshifted I2C address: 0x43
CLOSE jumper to add I2C pullups to bus
Cut jumpers to disable LEDs
Paul Clark
Headers
LEDs
L-Band Corrections Module: u-blox NEO-D9S
L1/L2/L-Band Antenna
USB
VCC Range: 3.0 - 3.6V
Cut jumpers to isolate shields
50Ω
Cut track to disable VCC_RF antenna power
90Ω
When populating L1: use an 0603 part with impedance > 500 Ohms at 1.5GHz
Iout (max): 600mA Vin (max): 6.5V Vdrop (max): 250mV Iq: 55uA
7-bit unshifted I2C address: 0x42
GNSS Module: u-blox ZED-F9P
Antenna Divider - BP2G1+
Jumpers
Backup Battery
Cut jumpers to isolate UART2
Voltage Regulation - AP2112K
RF Track Impedance: Coplanar Waveguide with Ground Calculations https://chemandy.com/calculators/coplanar-waveguide-with-ground-calculator.htm Ground is on layer 2. Prepreg thickness: 0.2mm. Er = 4.6 12.5 mil track with 5 mil gap = 50 Ohms
UART2 Link for PMP Corrections ZED-F9P <-> NEO-D9S
Revised By: Elias Santistevan
USB Track Impedance: Differential Pair https://saturnpcb.com/saturn-pcb-toolkit/ Prepreg thickness: 0.2mm (7.1 mil). Er = 4.6 8 mil track with 5 mil gap (13 mil center to center) = 90 Ohms

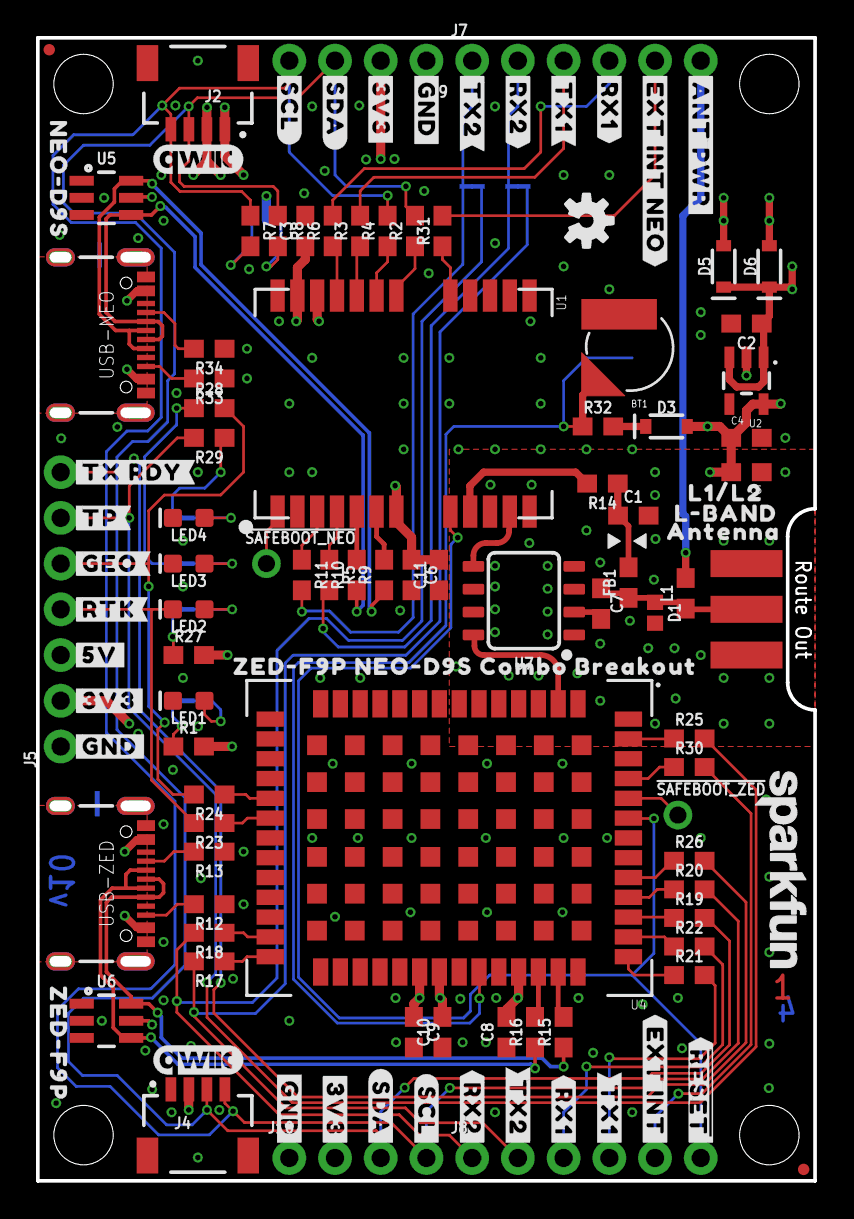
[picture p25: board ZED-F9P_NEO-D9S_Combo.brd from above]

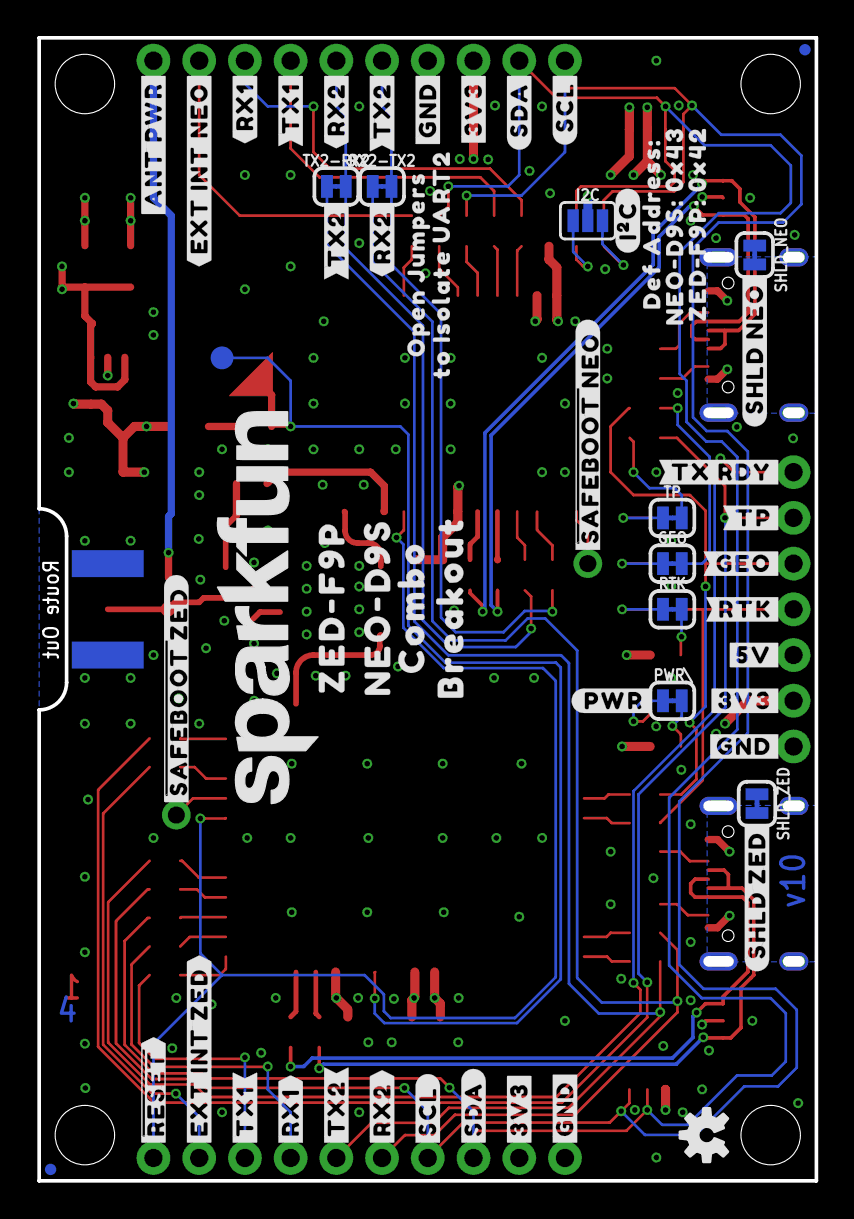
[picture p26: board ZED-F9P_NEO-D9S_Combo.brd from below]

Board: 4 copper layers, 43.2 x 63.5 mm, 179 parts (60 on the bottom side), 75 nets.

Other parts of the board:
LOGO1: OSHW-LOGOS; OSHW-LOGO-S
LOGO6: QWIIC_LOGO_5MM; QWIIC_5MM
U$1, U$2, U$3: #GND#0
U$4, U$5, U$6: #GND#1
U$7: #SHLD_ZED#15
U$8, U$10: #SDA#0
U$9, U$13: #SCL#0
U$11, U$12: #SDA#1
U$14: L#BAND18
U$15, U$30: #SCL#1
U$16: #RTK#0
U$17: #RTK#1
U$18: #GEO#0
U$19: #GEO#1
U$20: #5V#0
U$21: #5V#6
U$22, U$23, U$56: #3V3#0
U$24, U$25, U$70: #3V3#4
U$26: #TP#0
U$27: #TP#1
U$28: #TX_RDY#0
U$29: #TX_RDY#1
U$31, U$39, U$40: #TX2#0
U$32, U$34, U$35: #RX2#0
U$33: L1#L218
U$36, U$37: #RX2#3
U$41, U$42: #TX2#3
U$43, U$44: #RX1#0
U$45: ##RESET##0
U$46: ##RESET##1
U$47: #EXT_INT#0
U$48: #EXT_INT_ZED#0
U$49, U$50: #RX1#2
U$51, U$57: #TX1#0
U$52: #I�C#0
U$53: #SHLD_NEO#12
U$54: ANTENNA18
U$55: NEO#D9S16
U$58: #ANT_PWR#0
U$59: #ANT_PWR#1
U$60, U$61: #TX1#2
U$62: #EXT_INT_NEO#0
U$63: #EXT_INT_NEO#1
U$64: COMBO16
U$65: ZED#F9P10
U$66: NEO#D9S10
U$67: BREAKOUT17
U$68: SFE_LOGO_NAME_.2
U$69: #PWR#0
U$71: ##SAFEBOOT#_NEO#13
U$72: ##SAFEBOOT#_ZED#14
U$73: OPEN_JUMPERS13
U$74: TO_ISOLATE_UART214
U$75: ZED#F9P_NEO#D9S_COMBO_BREAKOUT0
U$76: DEF_ADDRESS#_12
U$78: ZED#F9P16
U$79: NEO#D9S#13
U$80: ZED#F9P#13
U$81: 0X4313
U$82: 0X4213

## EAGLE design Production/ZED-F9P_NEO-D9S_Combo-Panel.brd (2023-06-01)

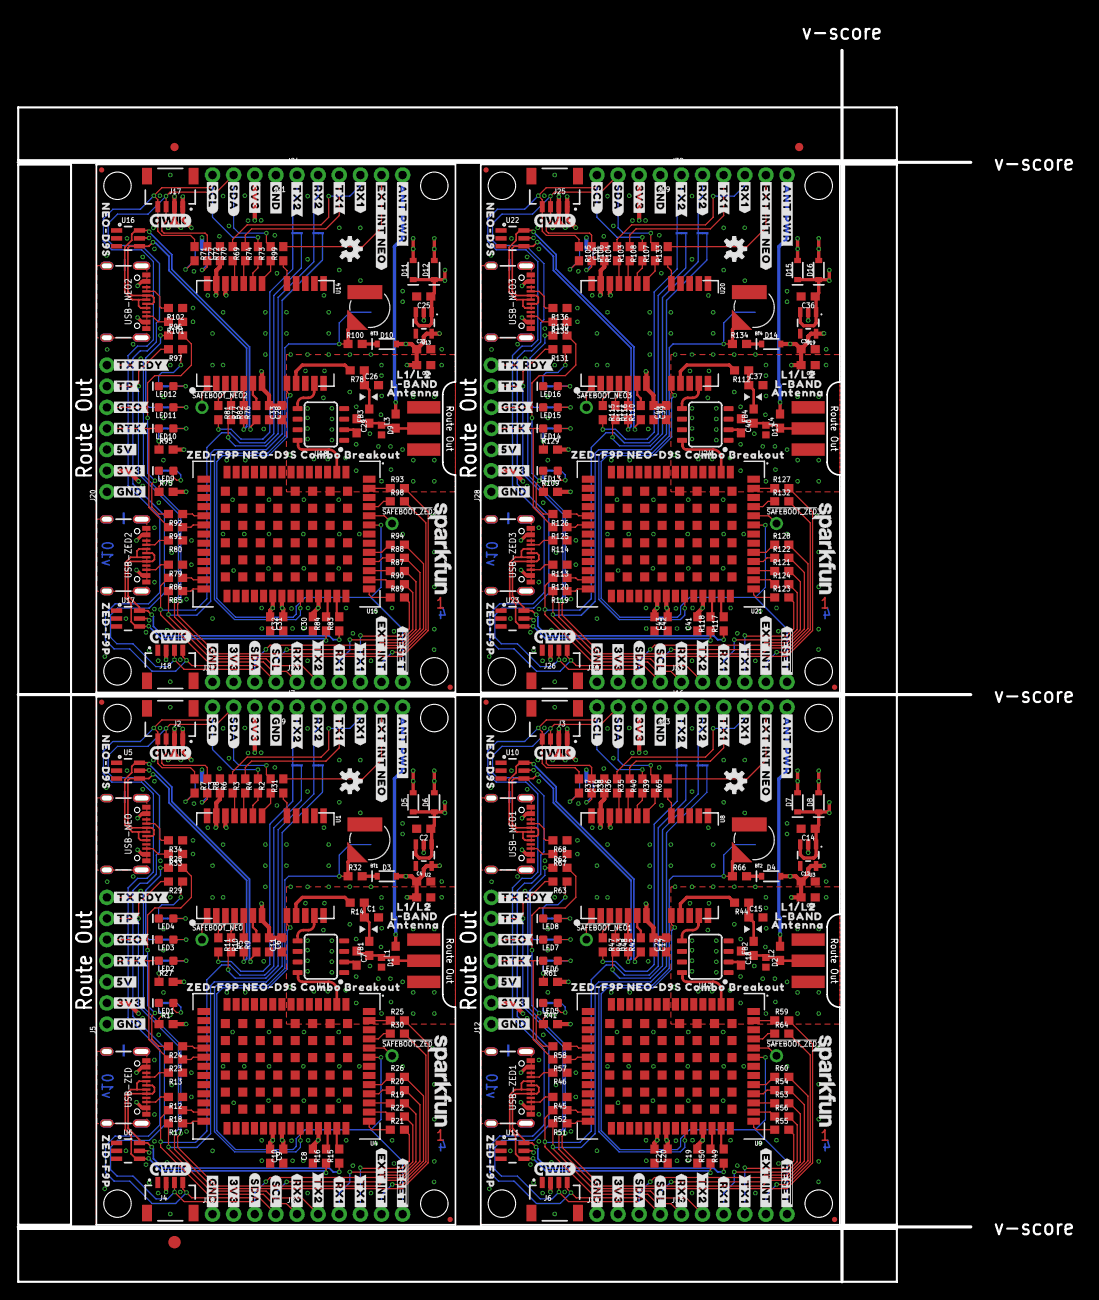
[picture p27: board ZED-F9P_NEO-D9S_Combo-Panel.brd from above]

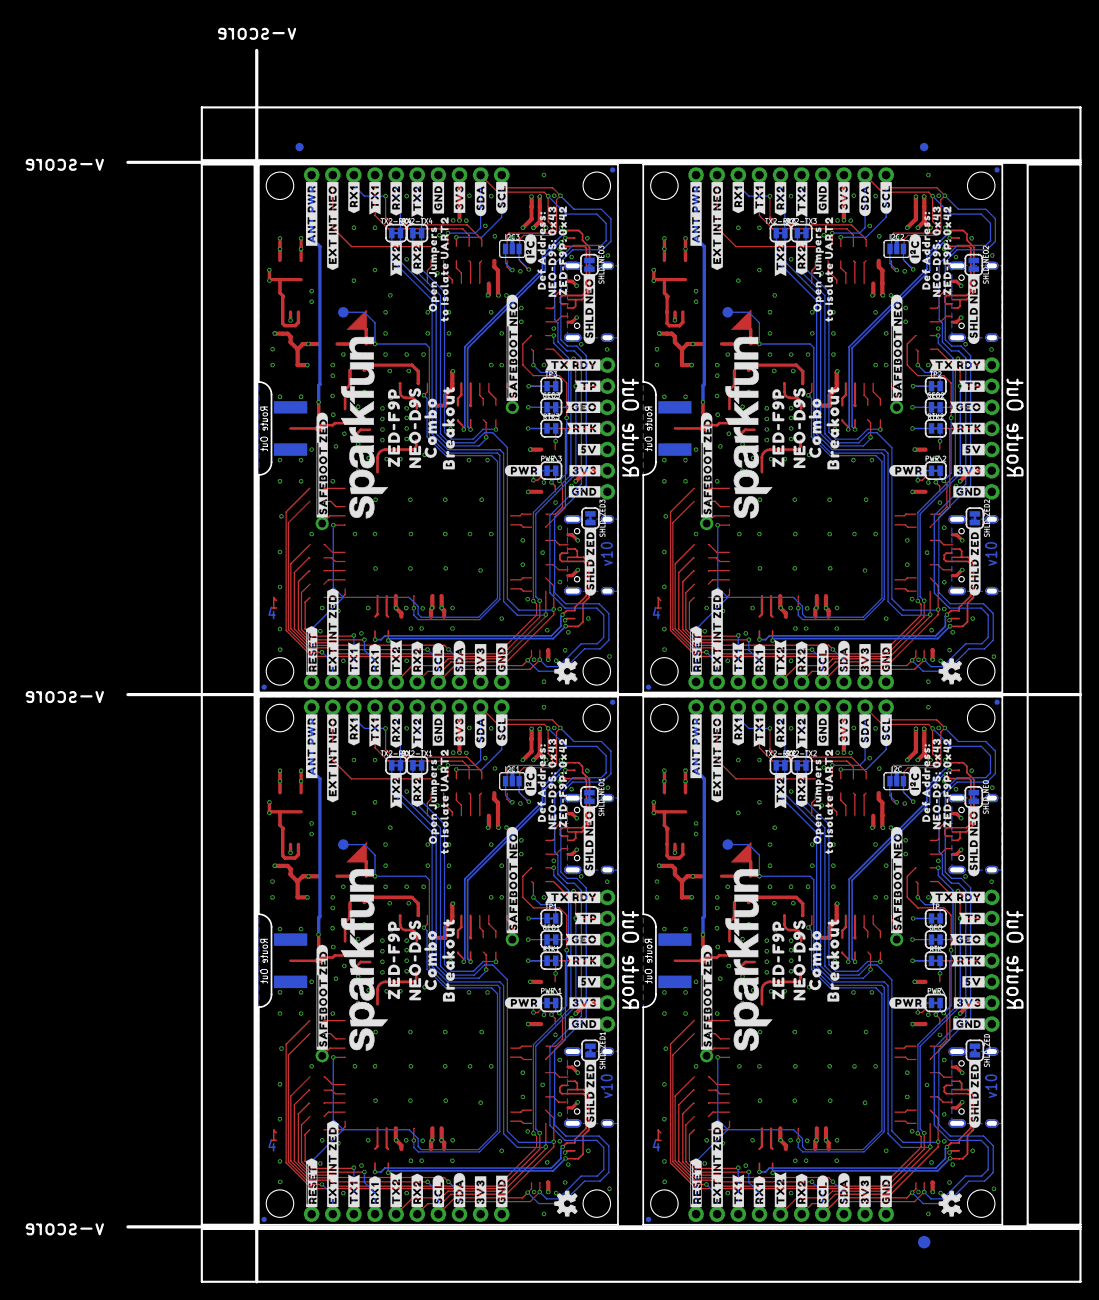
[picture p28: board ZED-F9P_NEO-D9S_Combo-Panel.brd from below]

Board: 4 copper layers, 114.6 x 148.1 mm, 714 parts (243 on the bottom side), 300 nets.

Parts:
!SAFEBOOT_NEO!, !SAFEBOOT_NEO!1, !SAFEBOOT_NEO!2, !SAFEBOOT_NEO!3: TEST-POINTPOGO_PTH; 1X01_NO_SILK
!SAFEBOOT_ZED!, !SAFEBOOT_ZED!1, !SAFEBOOT_ZED!2, !SAFEBOOT_ZED!3: TEST-POINTPOGO_PTH; 1X01_NO_SILK
BT1, BT2, BT3, BT4: RELOWABLE_BATTERY_MS421R; MS421R_IV03E
C1, C7, C15, C18, C26, C29, C37, C40: 47pF; 0603
C2, C3, C4, C6, C8, C9, C12, C14, C16, C17, C19, C20, C23, C25, C27, C28, C30, C31, C34, C36, C38, C39, C41, C42: 1.0uF; 0603
C5, C10, C11, C13, C21, C22, C24, C32, C33, C35, C43, C44: 0.1uF; 0603
D1, D2, D9, D13: PESD0402-0402; 0402
D3, D4, D10, D14: 0.5A/40V/420mV; SOD-323
D5, D6, D7, D8, D11, D12, D15, D16: 1A/23V/620mV; SOD-323
E$1, E$2, E$3, E$4: FIDUCIAL-1X2
E$5, E$6: FIDUCIAL-1.5X3
FB1, FB2, FB3, FB4: 30Ω/1.8A; 0603
GEO, GEO1, GEO2, GEO3: JUMPER-SMT_2_NC_TRACE_SILK; SMT-JUMPER_2_NC_TRACE_SILK
I2C, I2C1, I2C2, I2C3: JUMPER-SMT_3_NO_SILK; SMT-JUMPER_3_NO_SILK
J1, J11, J19, J27: ANTENNA-SMA-GROUNDEDEDGE_SMA; SMA-EDGE
J2, J3, J4, J6, J17, J18, J25, J26: Qwiic Right Angle; JST04_1MM_RA
J5, J12, J20, J28: 1X07_NO_SILK
J7, J8, J15, J16, J23, J24, J31, J32: 1X06_NO_SILK
J9, J10, J13, J14, J21, J22, J29, J30: 1X04_NO_SILK
JP1, JP2, JP7, JP8, JP9, JP10, JP15, JP16, JP17, JP18, JP24, JP25, JP31, JP41, JP91, JP101: STAND-OFF
JP3, JP4, JP5, JP6, JP11, JP12, JP13, JP14, JP19, JP20, JP21, JP22, JP23, JP61, JP71, JP81: FIDUCIALUFIDUCIAL; MICRO-FIDUCIAL
L1, L2, L3, L4: DNP; 0603_NO-CREAM
LED1, LED5, LED9, LED13: RED; LED-0603
LED2, LED3, LED4, LED6, LED7, LED8, LED10, LED11, LED12, LED14, LED15, LED16: BLUE; LED-0603
LOGO1, LOGO4, LOGO5, LOGO7, LOGO11, LOGO12, LOGO16, LOGO17: OSHW-LOGOS; OSHW-LOGO-S
LOGO2, LOGO8, LOGO13, LOGO18: SFE_LOGO_NAME.1_INCH; SFE_LOGO_NAME_.1
LOGO3, LOGO6, LOGO9, LOGO10, LOGO14, LOGO15, LOGO19, LOGO20: QWIIC_LOGO_5MM; QWIIC_5MM
PWR\, PWR\1, PWR\2, PWR\3: JUMPER-SMT_2_NC_TRACE_SILK; SMT-JUMPER_2_NC_TRACE_SILK
R1, R41, R75, R109: 4.7k; 0603
R2, R3, R4, R5, R6, R11, R17, R18, R19, R20, R21, R22, R23, R24, R25, R26, R30, R31, R35, R36, R39, R40, R47, R48, R51, R52, R53, R54, R55, R56, R57, R58, R59, R60, R64, R65, R69, R70, R73, R74, R81, R82, R85, R86, R87, R88, R89, R90, R91, R92, R93, R94, R98, R99, R103, R104, R107, R108, R115, R116, R119, R120, R121, R122, R123, R124, R125, R126, R127, R128, R132, R133: 33; 0603
R7, R8, R37, R38, R71, R72, R105, R106: 2.2k; 0603
R9, R10, R15, R16, R42, R43, R49, R50, R76, R77, R83, R84, R110, R111, R117, R118: 27; 0603
R12, R13, R33, R34, R45, R46, R67, R68, R79, R80, R101, R102, R113, R114, R135, R136: 5.1k; 0603
R14, R44, R78, R112: 10; 0603
R27, R28, R29, R61, R62, R63, R95, R96, R97, R129, R130, R131: 1k; 0603
R32, R66, R100, R134: 3.3k; 0603
RTK, RTK1, RTK2, RTK3: JUMPER-SMT_2_NC_TRACE_SILK; SMT-JUMPER_2_NC_TRACE_SILK
RX2-TX1, RX2-TX2, RX2-TX3, RX2-TX4: JUMPER-SMT_2_NC_TRACE_SILK; SMT-JUMPER_2_NC_TRACE_SILK
SHLD_NEO, SHLD_NEO1, SHLD_NEO2, SHLD_NEO3: JUMPER-SMT_2_NC_TRACE_SILK; SMT-JUMPER_2_NC_TRACE_SILK
SHLD_ZED, SHLD_ZED1, SHLD_ZED2, SHLD_ZED3: JUMPER-SMT_2_NC_TRACE_SILK; SMT-JUMPER_2_NC_TRACE_SILK
TP, TP1, TP2, TP3: JUMPER-SMT_2_NC_TRACE_SILK; SMT-JUMPER_2_NC_TRACE_SILK
TX2-RX1, TX2-RX2, TX2-RX3, TX2-RX4: JUMPER-SMT_2_NC_TRACE_SILK; SMT-JUMPER_2_NC_TRACE_SILK
U1, U8, U14, U20: U-BLOX_NEO-D9S-00B; NEO-M9N/M8T/M8U/D9S
U2, U3, U13, U19: 3.3V; SOT23-5
U4, U9, U15, U21: U-BLOX_ZED-F9P; ZED-F9P
U5, U6, U10, U11, U16, U17, U22, U23: ESD Diode; SOT-23-6
U7, U12, U18, U24: BP2G1+_POWER_SPLITTER; XX21
U$1, U$2, U$3, U$38, U$77, U$83, U$161, U$162, U$163, U$241, U$242, U$243: #GND#0
U$4, U$5, U$6, U$84, U$85, U$86, U$164, U$165, U$166, U$244, U$245, U$246: #GND#1
U$7, U$144, U$224, U$304: #SHLD_ZED#15
U$8, U$10, U$126, U$127, U$206, U$207, U$286, U$287: #SDA#0
U$9, U$13, U$130, U$131, U$210, U$211, U$290, U$291: #SCL#0
U$11, U$12, U$128, U$129, U$208, U$209, U$288, U$289: #SDA#1
U$14, U$153, U$233, U$313: L#BAND18
U$15, U$30, U$132, U$133, U$212, U$213, U$292, U$293: #SCL#1
U$16, U$100, U$180, U$260: #RTK#0
U$17, U$101, U$181, U$261: #RTK#1
U$18, U$102, U$182, U$262: #GEO#0
U$19, U$103, U$183, U$263: #GEO#1
U$20, U$87, U$167, U$247: #5V#0
U$21, U$88, U$168, U$248: #5V#6
U$22, U$23, U$56, U$89, U$90, U$97, U$169, U$170, U$177, U$249, U$250, U$257: #3V3#0
U$24, U$25, U$70, U$91, U$92, U$139, U$171, U$172, U$219, U$251, U$252, U$299: #3V3#4
U$26, U$104, U$184, U$264: #TP#0
U$27, U$105, U$185, U$265: #TP#1
U$28, U$106, U$186, U$266: #TX_RDY#0
U$29, U$107, U$187, U$267: #TX_RDY#1
U$31, U$39, U$40, U$112, U$113, U$134, U$192, U$193, U$214, U$272, U$273, U$294: #TX2#0
U$32, U$34, U$35, U$108, U$109, U$135, U$188, U$189, U$215, U$268, U$269, U$295: #RX2#0
U$33, U$151, U$231, U$311: L1#L218
U$36, U$37, U$110, U$111, U$190, U$191, U$270, U$271: #RX2#3
U$41, U$42, U$114, U$115, U$194, U$195, U$274, U$275: #TX2#3
U$43, U$44, U$116, U$117, U$196, U$197, U$276, U$277: #RX1#0
U$45, U$93, U$173, U$253: ##RESET##0
U$46, U$94, U$174, U$254: ##RESET##1
U$47, U$95, U$175, U$255: #EXT_INT#0
U$48, U$140, U$220, U$300: #EXT_INT_ZED#0
U$49, U$50, U$118, U$119, U$198, U$199, U$278, U$279: #RX1#2
U$51, U$57, U$120, U$121, U$200, U$201, U$280, U$281: #TX1#0
U$52, U$96, U$176, U$256: #I�C#0
U$53, U$145, U$225, U$305: #SHLD_NEO#12
U$54, U$152, U$232, U$312: ANTENNA18
U$55, U$147, U$227, U$307: NEO#D9S16
U$58, U$98, U$178, U$258: #ANT_PWR#0
U$59, U$99, U$179, U$259: #ANT_PWR#1
U$60, U$61, U$122, U$123, U$202, U$203, U$282, U$283: #TX1#2
U$62, U$124, U$204, U$284: #EXT_INT_NEO#0
U$63, U$125, U$205, U$285: #EXT_INT_NEO#1
U$64, U$148, U$228, U$308: COMBO16
U$65, U$136, U$216, U$296: ZED#F9P10
U$66, U$137, U$217, U$297: NEO#D9S10
U$67, U$149, U$229, U$309: BREAKOUT17
U$68, U$150, U$230, U$310: SFE_LOGO_NAME_.2
U$69, U$138, U$218, U$298: #PWR#0
U$71, U$142, U$222, U$302: ##SAFEBOOT#_NEO#13
U$72, U$143, U$223, U$303: ##SAFEBOOT#_ZED#14
U$73, U$154, U$234, U$314: OPEN_JUMPERS13
U$74, U$155, U$235, U$315: TO_ISOLATE_UART214
U$75, U$141, U$221, U$301: ZED#F9P_NEO#D9S_COMBO_BREAKOUT0
U$76, U$156, U$236, U$316: DEF_ADDRESS#_12
U$78, U$146, U$226, U$306: ZED#F9P16
U$79, U$157, U$237, U$317: NEO#D9S#13
U$80, U$158, U$238, U$318: ZED#F9P#13
U$81, U$159, U$239, U$319: 0X4313
U$82, U$160, U$240, U$320: 0X4213
USB-NEO, USB-NEO1, USB-NEO2, USB-NEO3: USB Female Type C Connector; USB-C-16P_4LAYER-PADS
USB-ZED, USB-ZED1, USB-ZED2, USB-ZED3: USB Female Type C Connector; USB-C-16P_4LAYER-PADS
V_BKCP, V_BKCP1, V_BKCP2, V_BKCP3: TEST-POINT3X5; PAD.03X.05

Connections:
3.3V: C3.1, C4.1, C5.2, C6.1, C8.2, C9.1, C10.2, C11.2, D3.A, I2C.2, J2.2, J4.2, J5.2, J9.2, J10.2, R1.2, R27.2, U1.7, U1.22, U1.23, U2.5, U4.33, U4.34, U4.38
3.3V1: C12.1, C13.2, C16.1, C17.1, C19.2, C20.1, C21.2, C22.2, D4.A, I2C1.2, J3.2, J6.2, J12.2, J13.2, J14.2, R41.2, R61.2, U3.5, U8.7, U8.22, U8.23, U9.33, U9.34, U9.38
3.3V2: C23.1, C24.2, C27.1, C28.1, C30.2, C31.1, C32.2, C33.2, D10.A, I2C2.2, J17.2, J18.2, J20.2, J21.2, J22.2, R75.2, R95.2, U13.5, U14.7, U14.22, U14.23, U15.33, U15.34, U15.38
3.3V3: C34.1, C35.2, C38.1, C39.1, C41.2, C42.1, C43.2, C44.2, D14.A, I2C3.2, J25.2, J26.2, J28.2, J29.2, J30.2, R109.2, R129.2, U19.5, U20.7, U20.22, U20.23, U21.33, U21.34, U21.38
5V: C2.1, D5.C, D6.C, J5.3, U2.1, U2.3
5V1: C14.1, D7.C, D8.C, J12.3, U3.1, U3.3
5V2: C25.1, D11.C, D12.C, J20.3, U13.1, U13.3
5V3: C36.1, D15.C, D16.C, J28.3, U19.1, U19.3
!RESET!: J8.6, U1.8, U4.49
!RESET!1: J15.6, U8.8, U9.49
!RESET!2: J23.6, U14.8, U15.49
!RESET!3: J31.6, U20.8, U21.49
!SAFEBOOT_NEO!: !SAFEBOOT_NEO!.1, U1.1
!SAFEBOOT_NEO!1: !SAFEBOOT_NEO!1.1, U8.1
!SAFEBOOT_NEO!2: !SAFEBOOT_NEO!2.1, U14.1
!SAFEBOOT_NEO!3: !SAFEBOOT_NEO!3.1, U20.1
!SAFEBOOT_ZED!: !SAFEBOOT_ZED!.1, U4.50
!SAFEBOOT_ZED!1: !SAFEBOOT_ZED!1.1, U9.50
!SAFEBOOT_ZED!2: !SAFEBOOT_ZED!2.1, U15.50
!SAFEBOOT_ZED!3: !SAFEBOOT_ZED!3.1, U21.50
ANT: C7.2, U7.2
ANT1: C18.2, U12.2
ANT2: C29.2, U18.2
ANT3: C40.2, U24.2
ANT_NEO: U1.11, U7.5
ANT_NEO1: U8.11, U12.5
ANT_NEO2: U14.11, U18.5
ANT_NEO3: U20.11, U24.5
ANT_PWR: J7.6, L1.2
ANT_PWR1: J16.6, L2.2
ANT_PWR2: J24.6, L3.2
ANT_PWR3: J32.6, L4.2
ANT_VCC: C1.1, FB1.2, R14.1
ANT_VCC1: C15.1, FB2.2, R44.1
ANT_VCC2: C26.1, FB3.2, R78.1
ANT_VCC3: C37.1, FB4.2, R112.1
ANT_ZED: U4.2, U7.8
ANT_ZED1: U9.2, U12.8
ANT_ZED2: U15.2, U18.8
ANT_ZED3: U21.2, U24.8
D+_NEO: R9.1, U5.6, USB-NEO.A6, USB-NEO.B6
D+_NEO1: R42.1, U10.6, USB-NEO1.A6, USB-NEO1.B6
D+_NEO2: R76.1, U16.6, USB-NEO2.A6, USB-NEO2.B6
D+_NEO3: R110.1, U22.6, USB-NEO3.A6, USB-NEO3.B6
D+_ZED: R15.1, U6.6, USB-ZED.A6, USB-ZED.B6
D+_ZED1: R49.1, U11.6, USB-ZED1.A6, USB-ZED1.B6
D+_ZED2: R83.1, U17.6, USB-ZED2.A6, USB-ZED2.B6
D+_ZED3: R117.1, U23.6, USB-ZED3.A6, USB-ZED3.B6
D-_NEO: R10.1, U5.4, USB-NEO.A7, USB-NEO.B7
D-_NEO1: R43.1, U10.4, USB-NEO1.A7, USB-NEO1.B7
D-_NEO2: R77.1, U16.4, USB-NEO2.A7, USB-NEO2.B7
D-_NEO3: R111.1, U22.4, USB-NEO3.A7, USB-NEO3.B7
D-_ZED: R16.1, U6.4, USB-ZED.A7, USB-ZED.B7
D-_ZED1: R50.1, U11.4, USB-ZED1.A7, USB-ZED1.B7
D-_ZED2: R84.1, U17.4, USB-ZED2.A7, USB-ZED2.B7
D-_ZED3: R118.1, U23.4, USB-ZED3.A7, USB-ZED3.B7
EXT_INT_NEO: J7.5, R31.2
EXT_INT_NEO1: J16.5, R65.2
EXT_INT_NEO2: J24.5, R99.2
EXT_INT_NEO3: J32.5, R133.2
EXT_INT_ZED: J8.5, R30.2
EXT_INT_ZED1: J15.5, R64.2
EXT_INT_ZED2: J23.5, R98.2
EXT_INT_ZED3: J31.5, R132.2
GEO: J5.5, R24.2, R28.2
GEO1: J12.5, R58.2, R62.2
GEO2: J20.5, R92.2, R96.2
GEO3: J28.5, R126.2, R130.2
GND: BT1.-, C1.2, C2.2, C3.2, C4.2, C5.1, C6.2, C8.1, C9.2, C10.1, C11.1, D1.2, J1.GND@0, J1.GND@1, J1.GND@2, J1.GND@3, J2.1, J4.1, J5.1, J9.1, J10.1, LED1.C, LED3.C, LED4.C, R12.1, R13.1, R33.1, R34.1, SHLD_NEO.1, SHLD_ZED.1, U1.10, U1.12, U1.13, U1.24, U2.2, U4.1, U4.3, U4.12, U4.14, U4.32, U4.37, U4.41, U4.48, U4.55, U4.56, U4.57, U4.58, U4.59, U4.60, U4.61, U4.62, U4.63, U4.64, U4.65, U4.66, U4.67, U4.68, U4.69, U4.70, U4.71, U4.72, U4.73, U4.74, U4.75, U4.76, U4.77, U4.78, U4.79, U4.80, U4.81, U4.82, U4.83, U4.84, U4.85, U4.86, U4.87, U4.88, U4.89, U4.90, U4.91, U4.92, U4.93, U4.94, U4.95, U4.96, U4.97, U4.98, U4.99, U4.100, U4.101, U4.102, U5.2, U6.2, U7.1, U7.3, U7.4, U7.6, U7.7, USB-NEO.GND, USB-NEO.GND2, USB-ZED.GND, USB-ZED.GND2
GND1: BT2.-, C12.2, C13.1, C14.2, C15.2, C16.2, C17.2, C19.1, C20.2, C21.1, C22.1, D2.2, J3.1, J6.1, J11.GND@0, J11.GND@1, J11.GND@2, J11.GND@3, J12.1, J13.1, J14.1, LED5.C, LED7.C, LED8.C, R45.1, R46.1, R67.1, R68.1, SHLD_NEO1.1, SHLD_ZED1.1, U3.2, U8.10, U8.12, U8.13, U8.24, U9.1, U9.3, U9.12, U9.14, U9.32, U9.37, U9.41, U9.48, U9.55, U9.56, U9.57, U9.58, U9.59, U9.60, U9.61, U9.62, U9.63, U9.64, U9.65, U9.66, U9.67, U9.68, U9.69, U9.70, U9.71, U9.72, U9.73, U9.74, U9.75, U9.76, U9.77, U9.78, U9.79, U9.80, U9.81, U9.82, U9.83, U9.84, U9.85, U9.86, U9.87, U9.88, U9.89, U9.90, U9.91, U9.92, U9.93, U9.94, U9.95, U9.96, U9.97, U9.98, U9.99, U9.100, U9.101, U9.102, U10.2, U11.2, U12.1, U12.3, U12.4, U12.6, U12.7, USB-NEO1.GND, USB-NEO1.GND2, USB-ZED1.GND, USB-ZED1.GND2
GND2: BT3.-, C23.2, C24.1, C25.2, C26.2, C27.2, C28.2, C30.1, C31.2, C32.1, C33.1, D9.2, J17.1, J18.1, J19.GND@0, J19.GND@1, J19.GND@2, J19.GND@3, J20.1, J21.1, J22.1, LED9.C, LED11.C, LED12.C, R79.1, R80.1, R101.1, R102.1, SHLD_NEO2.1, SHLD_ZED2.1, U13.2, U14.10, U14.12, U14.13, U14.24, U15.1, U15.3, U15.12, U15.14, U15.32, U15.37, U15.41, U15.48, U15.55, U15.56, U15.57, U15.58, U15.59, U15.60, U15.61, U15.62, U15.63, U15.64, U15.65, U15.66, U15.67, U15.68, U15.69, U15.70, U15.71, U15.72, U15.73, U15.74, U15.75, U15.76, U15.77, U15.78, U15.79, U15.80, U15.81, U15.82, U15.83, U15.84, U15.85, U15.86, U15.87, U15.88, U15.89, U15.90, U15.91, U15.92, U15.93, U15.94, U15.95, U15.96, U15.97, U15.98, U15.99, U15.100, U15.101, U15.102, U16.2, U17.2, U18.1, U18.3, U18.4, U18.6, U18.7, USB-NEO2.GND, USB-NEO2.GND2, USB-ZED2.GND, USB-ZED2.GND2
GND3: BT4.-, C34.2, C35.1, C36.2, C37.2, C38.2, C39.2, C41.1, C42.2, C43.1, C44.1, D13.2, J25.1, J26.1, J27.GND@0, J27.GND@1, J27.GND@2, J27.GND@3, J28.1, J29.1, J30.1, LED13.C, LED15.C, LED16.C, R113.1, R114.1, R135.1, R136.1, SHLD_NEO3.1, SHLD_ZED3.1, U19.2, U20.10, U20.12, U20.13, U20.24, U21.1, U21.3, U21.12, U21.14, U21.32, U21.37, U21.41, U21.48, U21.55, U21.56, U21.57, U21.58, U21.59, U21.60, U21.61, U21.62, U21.63, U21.64, U21.65, U21.66, U21.67, U21.68, U21.69, U21.70, U21.71, U21.72, U21.73, U21.74, U21.75, U21.76, U21.77, U21.78, U21.79, U21.80, U21.81, U21.82, U21.83, U21.84, U21.85, U21.86, U21.87, U21.88, U21.89, U21.90, U21.91, U21.92, U21.93, U21.94, U21.95, U21.96, U21.97, U21.98, U21.99, U21.100, U21.101, U21.102, U22.2, U23.2, U24.1, U24.3, U24.4, U24.6, U24.7, USB-NEO3.GND, USB-NEO3.GND2, USB-ZED3.GND, USB-ZED3.GND2
unnamed: PWR\.2, R1.1
unnamed: R3.1, U1.20
unnamed: R2.1, U1.18
unnamed: R4.1, U1.19
unnamed: I2C.1, R8.2
unnamed: R6.1, U1.21
unnamed: R12.2, USB-ZED.B5
unnamed: I2C.3, R7.2
unnamed: R13.2, USB-ZED.A5
unnamed: LED1.A, PWR\.1
unnamed: R9.2, U1.6
unnamed: R10.2, U1.5
unnamed: D3.C, R32.2
unnamed: R11.1, U1.3
unnamed: R5.1, U1.4
unnamed: R15.2, U4.40
unnamed: R16.2, U4.39
unnamed: R19.1, U4.44
unnamed: R20.1, U4.45
unnamed: R21.1, U4.42
unnamed: R22.1, U4.43
unnamed: R26.1, U4.46
unnamed: LED2.A, RTK.1
unnamed: R17.1, U4.27
unnamed: R18.1, U4.26
unnamed: GEO.1, LED3.A
unnamed: LED4.A, TP.1
unnamed: R27.1, RTK.2
unnamed: GEO.2, R28.1
unnamed: R29.1, TP.2
unnamed: R30.1, U4.51
unnamed: R31.1, U1.17
unnamed: R33.2, USB-NEO.B5
unnamed: R34.2, USB-NEO.A5
unnamed: R23.1, U4.20
unnamed: R24.1, U4.19
unnamed: R25.1, U4.53
unnamed: I2C1.1, R38.2
unnamed: I2C1.3, R37.2
unnamed: R42.2, U8.6
unnamed: R43.2, U8.5
unnamed: R45.2, USB-ZED1.B5
unnamed: R46.2, USB-ZED1.A5
unnamed: R47.1, U8.3
unnamed: R48.1, U8.4
unnamed: R35.1, U8.20
unnamed: R36.1, U8.21
unnamed: R39.1, U8.18
unnamed: R40.1, U8.19
unnamed: R49.2, U9.40
unnamed: R50.2, U9.39
unnamed: R53.1, U9.44
unnamed: R54.1, U9.45
unnamed: R55.1, U9.42
unnamed: R56.1, U9.43
unnamed: R51.1, U9.27
unnamed: R52.1, U9.26
unnamed: R60.1, U9.46
unnamed: LED6.A, RTK1.1
unnamed: GEO1.1, LED7.A
unnamed: LED8.A, TP1.1
unnamed: R61.1, RTK1.2
unnamed: GEO1.2, R62.1
unnamed: R63.1, TP1.2
unnamed: R57.1, U9.20
unnamed: R58.1, U9.19
unnamed: R59.1, U9.53
unnamed: R64.1, U9.51
unnamed: R65.1, U8.17
unnamed: D4.C, R66.2
unnamed: R67.2, USB-NEO1.B5
unnamed: R68.2, USB-NEO1.A5
unnamed: PWR\1.2, R41.1
unnamed: LED5.A, PWR\1.1
unnamed: I2C2.1, R72.2
unnamed: I2C2.3, R71.2
unnamed: R76.2, U14.6
unnamed: R77.2, U14.5
unnamed: R79.2, USB-ZED2.B5
unnamed: R80.2, USB-ZED2.A5
unnamed: R81.1, U14.3
unnamed: R82.1, U14.4
unnamed: R69.1, U14.20
unnamed: R70.1, U14.21
unnamed: R73.1, U14.18
unnamed: R74.1, U14.19
unnamed: R83.2, U15.40
unnamed: R84.2, U15.39
unnamed: R87.1, U15.44
unnamed: R88.1, U15.45
unnamed: R89.1, U15.42
unnamed: R90.1, U15.43
unnamed: R85.1, U15.27
unnamed: R86.1, U15.26
unnamed: R94.1, U15.46
unnamed: LED10.A, RTK2.1
unnamed: GEO2.1, LED11.A
unnamed: LED12.A, TP2.1
unnamed: R95.1, RTK2.2
unnamed: GEO2.2, R96.1
unnamed: R97.1, TP2.2
unnamed: R91.1, U15.20
unnamed: R92.1, U15.19
unnamed: R93.1, U15.53
unnamed: R98.1, U15.51
unnamed: R99.1, U14.17
unnamed: D10.C, R100.2
unnamed: R101.2, USB-NEO2.B5
unnamed: R102.2, USB-NEO2.A5
unnamed: PWR\2.2, R75.1
unnamed: LED9.A, PWR\2.1
unnamed: I2C3.1, R106.2
unnamed: I2C3.3, R105.2
unnamed: R110.2, U20.6
unnamed: R111.2, U20.5
unnamed: R113.2, USB-ZED3.B5
unnamed: R114.2, USB-ZED3.A5
unnamed: R115.1, U20.3
unnamed: R116.1, U20.4
unnamed: R103.1, U20.20
unnamed: R104.1, U20.21
unnamed: R107.1, U20.18
unnamed: R108.1, U20.19
unnamed: R117.2, U21.40
unnamed: R118.2, U21.39
unnamed: R121.1, U21.44
unnamed: R122.1, U21.45
unnamed: R123.1, U21.42
unnamed: R124.1, U21.43
unnamed: R119.1, U21.27
unnamed: R120.1, U21.26
unnamed: R128.1, U21.46
unnamed: LED14.A, RTK3.1
unnamed: GEO3.1, LED15.A
unnamed: LED16.A, TP3.1
unnamed: R129.1, RTK3.2
unnamed: GEO3.2, R130.1
unnamed: R131.1, TP3.2
unnamed: R125.1, U21.20
unnamed: R126.1, U21.19
unnamed: R127.1, U21.53
unnamed: R132.1, U21.51
unnamed: R133.1, U20.17
unnamed: D14.C, R134.2
unnamed: R135.2, USB-NEO3.B5
unnamed: R136.2, USB-NEO3.A5
unnamed: PWR\3.2, R109.1
unnamed: LED13.A, PWR\3.1
RTK: J5.4, LED2.C, R23.2
RTK1: J12.4, LED6.C, R57.2
RTK2: J20.4, LED10.C, R91.2
RTK3: J28.4, LED14.C, R125.2
RXD1_NEO: J7.4, R6.2
RXD1_NEO1: J16.4, R36.2
RXD1_NEO2: J24.4, R70.2
RXD1_NEO3: J32.4, R104.2
RXD1_ZED: J8.3, R22.2
RXD1_ZED1: J15.3, R56.2
RXD1_ZED2: J23.3, R90.2
RXD1_ZED3: J31.3, R124.2
RXD2_NEO: J7.2, R5.2, TX2-RX2.2
RXD2_NEO1: J16.2, R48.2, TX2-RX1.2
RXD2_NEO2: J24.2, R82.2, TX2-RX3.2
RXD2_NEO3: J32.2, R116.2, TX2-RX4.2
RXD2_ZED: J8.1, R18.2, RX2-TX2.1
RXD2_ZED1: J15.1, R52.2, RX2-TX1.1
RXD2_ZED2: J23.1, R86.2, RX2-TX3.1
RXD2_ZED3: J31.1, R120.2, RX2-TX4.1
SCL: J2.4, J4.4, J9.4, J10.4, R4.2, R7.1, R20.2
SCL1: J3.4, J6.4, J13.4, J14.4, R37.1, R40.2, R54.2
SCL2: J17.4, J18.4, J21.4, J22.4, R71.1, R74.2, R88.2
SCL3: J25.4, J26.4, J29.4, J30.4, R105.1, R108.2, R122.2
SDA: J2.3, J4.3, J9.3, J10.3, R2.2, R8.1, R19.2
SDA1: J3.3, J6.3, J13.3, J14.3, R38.1, R39.2, R53.2
SDA2: J17.3, J18.3, J21.3, J22.3, R72.1, R73.2, R87.2
SDA3: J25.3, J26.3, J29.3, J30.3, R106.1, R107.2, R121.2
SHIELD_NEO: SHLD_NEO.2, USB-NEO.SHLD1, USB-NEO.SHLD2, USB-NEO.SHLD3, USB-NEO.SHLD4
SHIELD_NEO1: SHLD_NEO1.2, USB-NEO1.SHLD1, USB-NEO1.SHLD2, USB-NEO1.SHLD3, USB-NEO1.SHLD4
SHIELD_NEO2: SHLD_NEO2.2, USB-NEO2.SHLD1, USB-NEO2.SHLD2, USB-NEO2.SHLD3, USB-NEO2.SHLD4
SHIELD_NEO3: SHLD_NEO3.2, USB-NEO3.SHLD1, USB-NEO3.SHLD2, USB-NEO3.SHLD3, USB-NEO3.SHLD4
SHIELD_ZED: SHLD_ZED.2, USB-ZED.SHLD1, USB-ZED.SHLD2, USB-ZED.SHLD3, USB-ZED.SHLD4
SHIELD_ZED1: SHLD_ZED1.2, USB-ZED1.SHLD1, USB-ZED1.SHLD2, USB-ZED1.SHLD3, USB-ZED1.SHLD4
SHIELD_ZED2: SHLD_ZED2.2, USB-ZED2.SHLD1, USB-ZED2.SHLD2, USB-ZED2.SHLD3, USB-ZED2.SHLD4
SHIELD_ZED3: SHLD_ZED3.2, USB-ZED3.SHLD1, USB-ZED3.SHLD2, USB-ZED3.SHLD3, USB-ZED3.SHLD4
SMA: C7.1, D1.1, FB1.1, J1.SIG, L1.1
SMA1: C18.1, D2.1, FB2.1, J11.SIG, L2.1
SMA2: C29.1, D9.1, FB3.1, J19.SIG, L3.1
SMA3: C40.1, D13.1, FB4.1, J27.SIG, L4.1
TP: J5.6, R25.2, R29.2
TP1: J12.6, R59.2, R63.2
TP2: J20.6, R93.2, R97.2
TP3: J28.6, R127.2, R131.2
TXD1_NEO: J7.3, R3.2
TXD1_NEO1: J16.3, R35.2
TXD1_NEO2: J24.3, R69.2
TXD1_NEO3: J32.3, R103.2
TXD1_ZED: J8.4, R21.2
TXD1_ZED1: J15.4, R55.2
TXD1_ZED2: J23.4, R89.2
TXD1_ZED3: J31.4, R123.2
TXD2_NEO: J7.1, R11.2, RX2-TX2.2
TXD2_NEO1: J16.1, R47.2, RX2-TX1.2
TXD2_NEO2: J24.1, R81.2, RX2-TX3.2
TXD2_NEO3: J32.1, R115.2, RX2-TX4.2
TXD2_ZED: J8.2, R17.2, TX2-RX2.1
TXD2_ZED1: J15.2, R51.2, TX2-RX1.1
TXD2_ZED2: J23.2, R85.2, TX2-RX3.1
TXD2_ZED3: J31.2, R119.2, TX2-RX4.1
TX_RDY: J5.7, R26.2
TX_RDY1: J12.7, R60.2
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

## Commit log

2023-05-22 Initial transfer from SparkX repository
    [ZED-F9P_NEO-D9S_Combo-Panel.GBL, ZED-F9P_NEO-D9S_Combo-Panel.GBO, ZED-F9P_NEO-D9S_Combo-Panel.GBP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]
2023-05-24 Updates various text and symbols
    * Replaces ESD Diodes and Antenna Splitter Diode with larger packages
    [ZED-F9P_NEO-D9S_Combo.brd, ZED-F9P_NEO-D9S_Combo.sch]
2023-05-25 Changes 90 Ohm impedance calculation to decrease trace width
    * Adds additional measures
    * Updates silk
    * Adds polygons to USB shield
    * Adds four layer numbers
    * Updated ordering instructions
    * Routes new antenna splitter
    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
    [ZED-F9P_NEO-D9S_Combo.brd, ZED-F9P_NEO-D9S_Combo.sch]
2023-05-26 Fixes ESD diode
    * Adds L-Band text/silk to relevant Antenna notes
    [ZED-F9P_NEO-D9S_Combo.brd, ZED-F9P_NEO-D9S_Combo.sch]
2023-05-26 Re-adds UART text on UART Jumpers
    * Updates the default address text so it's not so wordy.
    [ZED-F9P_NEO-D9S_Combo.brd]
2023-05-26 Normalizes the drill sizes
    [ZED-F9P_NEO-D9S_Combo.brd]
2023-05-26 Adds a few vias, fixes some ground pour
    [ZED-F9P_NEO-D9S_Combo.brd]
2023-05-30 Updates note for USB 90 Ohm impedance calculation
    * Moves all silk out towards the PTH's
    [ZED-F9P_NEO-D9S_Combo.brd, ZED-F9P_NEO-D9S_Combo.sch]
2023-05-30 Updates BP2G1+ with minor corrections
    [ZED-F9P_NEO-D9S_Combo.brd, ZED-F9P_NEO-D9S_Combo.sch]
2023-05-30 Replaces 1x6 PTH connector with no SKU
    [ZED-F9P_NEO-D9S_Combo.brd, ZED-F9P_NEO-D9S_Combo.sch]
2023-05-30 Adds new panel
    [ZED-F9P_NEO-D9S_Combo-Panel.GBL, ZED-F9P_NEO-D9S_Combo-Panel.GBO, ZED-F9P_NEO-D9S_Combo-Panel.GBP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]
2023-06-01 Adds new panel - bottom silk change
    [ZED-F9P_NEO-D9S_Combo-Panel.brd, ZED-F9P_NEO-D9S_Combo.brd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]
2023-07-19 Initial checkin of docs
    Initial checkin of GitHub docs framework

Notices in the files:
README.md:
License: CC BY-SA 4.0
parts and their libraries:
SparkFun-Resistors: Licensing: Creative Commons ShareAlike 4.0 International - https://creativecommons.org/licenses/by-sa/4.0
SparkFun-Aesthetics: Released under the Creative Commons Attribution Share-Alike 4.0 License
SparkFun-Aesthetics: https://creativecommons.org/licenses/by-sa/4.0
